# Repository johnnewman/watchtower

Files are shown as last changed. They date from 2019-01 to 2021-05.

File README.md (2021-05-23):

<p align="center">
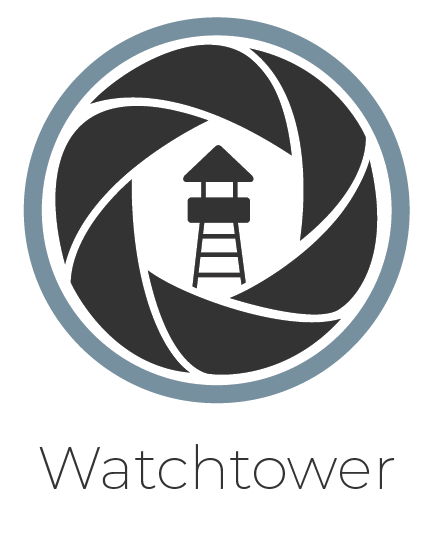
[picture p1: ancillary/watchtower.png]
  
</p>
<p class="aligncenter">

### Overview

Watchtower turns your Raspberry Pi into a DIY security camera. Watchtower scans for motion and, when triggered, will save a recording to disk in the h264 format and upload an encrypted copy to Dropbox. You can record to these destinations using different resolutions, which allows you to simultaneously record the full HD video to disk while recording a lower-resolution version to Dropbox.

The central [watchtower](watchtower) package is a Python 3 Flask app powered by uWSGI. It has API endpoints that allow you to start and stop monitoring, stream via MJPEG, record, download and delete recordings, and tweak camera settings. See [api.md](ancillary/api.md) for API documentation. This package also has an optional web app that provides a graphical interface for these APIs.

Watchtower was designed to take advantage of the Pi NoIR camera. An optional program for a microcontroller is included to read analog room brightness, control infrared LED intensity for night vision, move an optional servo, and communicate with Watchtower's microcontroller process using the Raspberry Pi's GPIO ports.

A 3D case for the system is located in [ancillary/case/](ancillary/case/). This case houses the Raspberry Pi, camera, microcontroller, servo, IR LEDs, fan, and more. A Fritzing diagram of the case's internal hardware is included in [ancillary/hardware/](ancillary/hardware).
<p align="center">
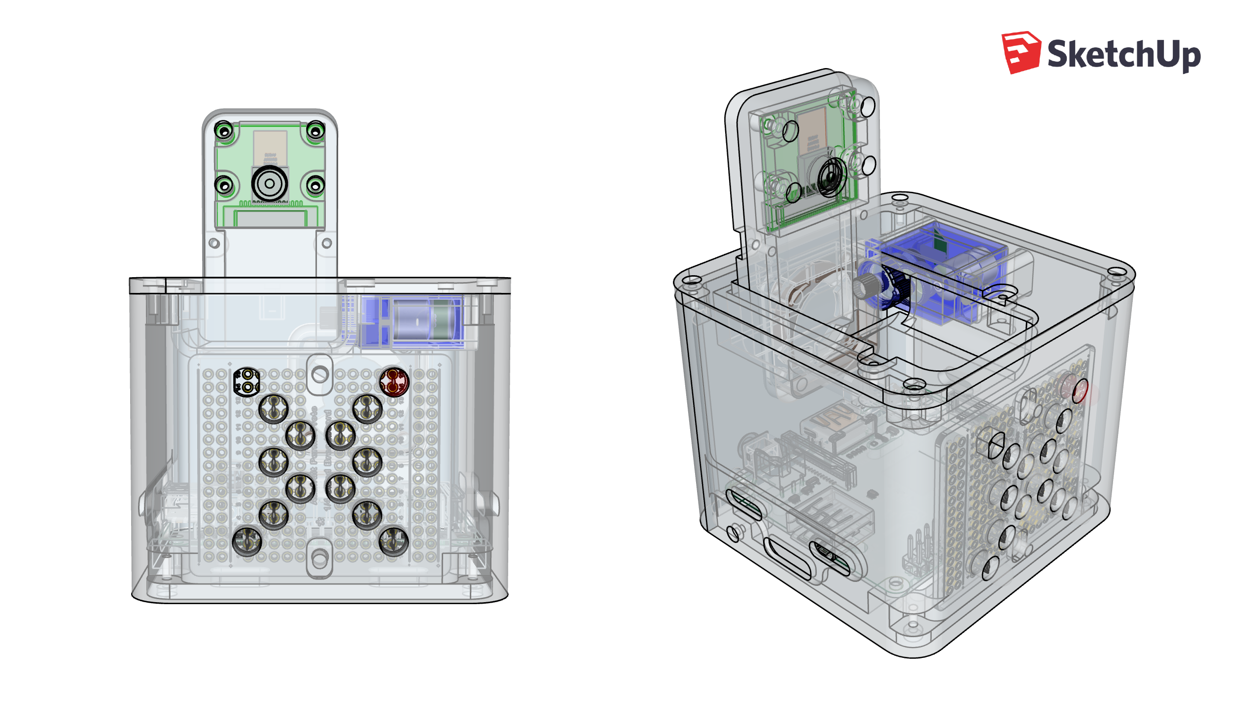
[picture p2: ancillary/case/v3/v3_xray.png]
    
</p>

### Setup

The Watchtower project is composed of multiple Docker containers that each carry out a specific function:
- the `app` container runs the main Watchtower package
- the `server` container runs an nginx app gateway and proxies requests to the `app` container
- the `motion` container continuously monitors the camera stream for motion
- the `mc_server` container communicates over a serial connection with an optional microcontroller
- the `icebox` container monitors the SoC temperature and controls an optional cooling fan via GPIO

_No container runs privileged as root. Only the minimum required access is provided to each container._

There is an included [install script](install.sh) for Raspberry Pi OS Lite that will set up Watchtower and place it behind a firewall. The install script only needs to be run once. After running, open a new shell session and run `docker-compose build` to build all of the containers. Finally, run ``docker-compose up -d` to start the application.

The final (and optional) steps outside of the script's scope are creating your SSL certificates for the web API and fine-tuning your Watchtower config file for Dropbox and microcontroller support.

Use the [WatchtowerServer project](https://github.com/johnnewman/watchtower_sever) as the main server that will handle traffic from the internet. That project is designed to proxy all requests to one of the upstream nginx servers running Watchtower. It can also coalesce the responses from all cameras into a single payload.

<p align="center">
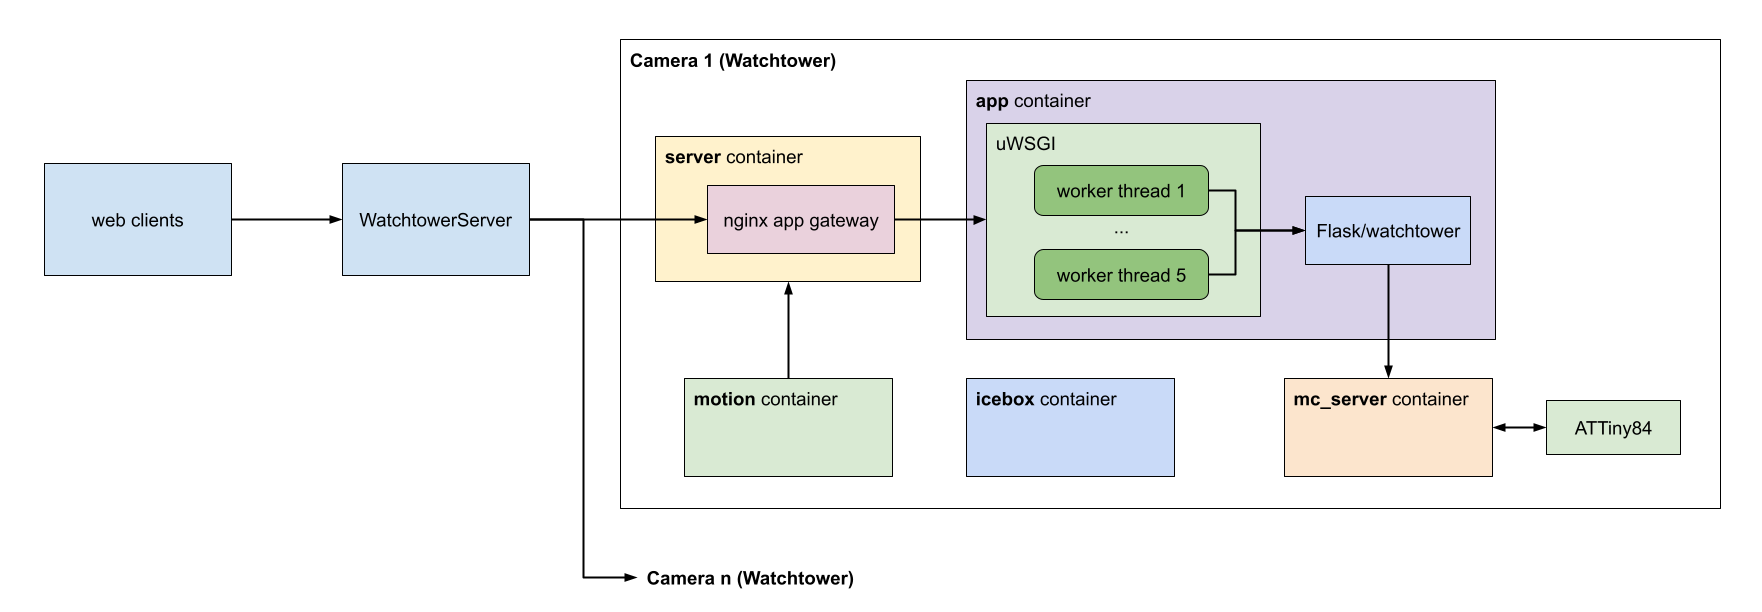
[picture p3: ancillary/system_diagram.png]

</p>

Both the reverse proxy and the upstream app gateway configurations encrypt all traffic and perform x509 client certificate authorization.

---

The rest of this readme breaks down each Watchtower component and describes its configuration. The three main configuration files are [config/watchtower_config.json](config/watchtower_config.json), [config/motion.conf](config/motion.conf), and the [.env](.env) file.
 1. [API endpoints](ancillary/api.md)
 2. [Front-end web app](#2-front-end-web-app)
 3. [Motion detection](#3-motion-detection)
 4. [Optional Dropbox file upload](#4-optional-dropbox-file-upload)
 5. [Optional microcontroller](#5-optional-microcontroller-infrared-and-servos)

### 1. API Endpoints

 Moved to [api.md](ancillary/api.md).

### 2. Front-end web app

An optional web app for each Pi's Watchtower instance can be enabled. You can access it in a browser through the reverse proxy by going to `https://proxy_address/camera0/`. This provides a simple interface for Watchtower built with [Bootstrap](https://getbootstrap.com/). 

The web app is broken into sections:
- The Home section lets you view the camera stream and toggle the monitoring status.
- The Recordings section displays a listing of all recordings that the Watchtower instance has saved. It allows you to delete and download individual recordings.
- The Settings section lets you tweak and save various settings of the Pi camera hardware.

| Home | Recordings | Settings |
| --- | --- | --- |
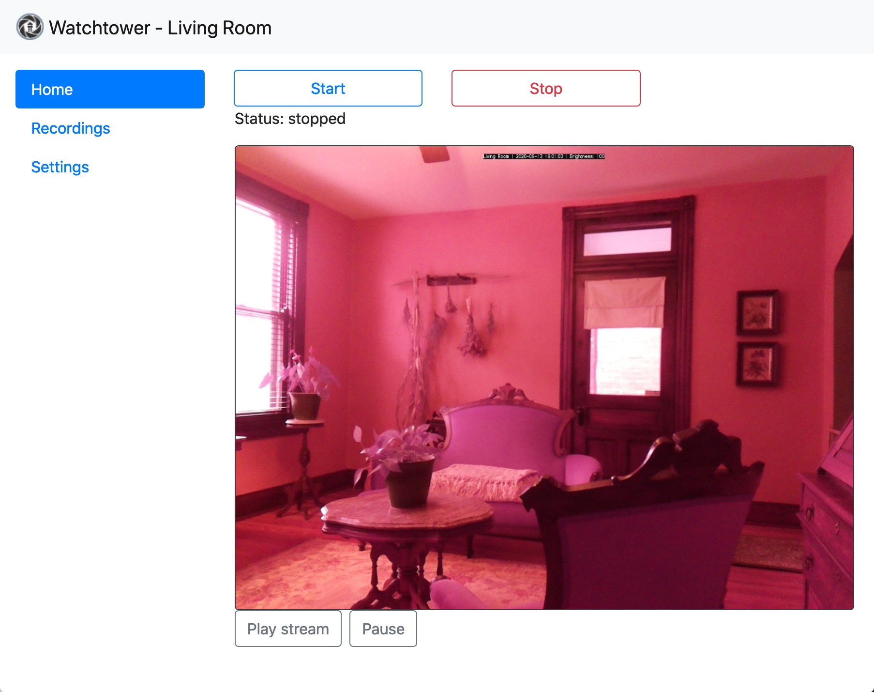
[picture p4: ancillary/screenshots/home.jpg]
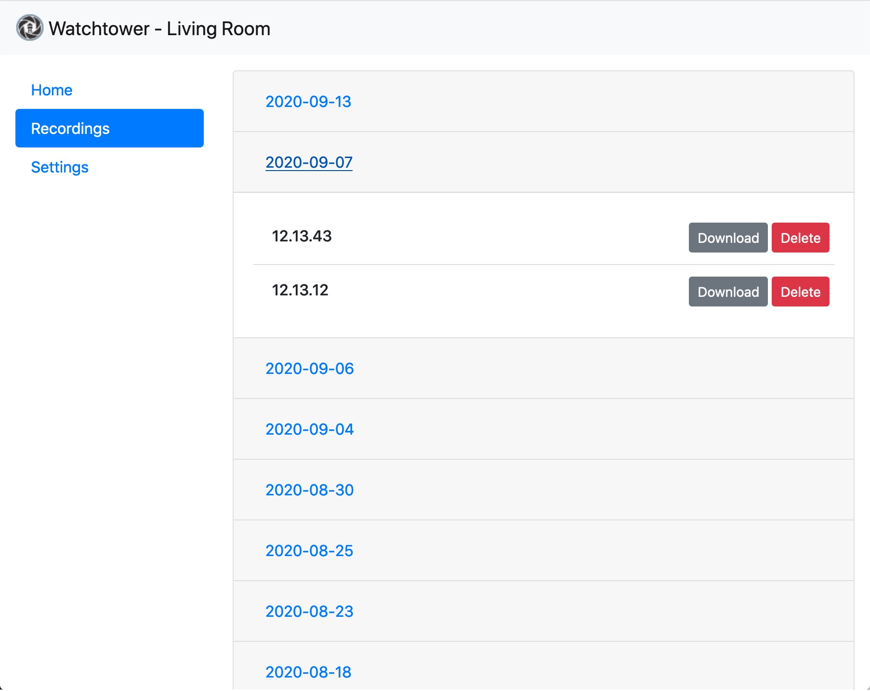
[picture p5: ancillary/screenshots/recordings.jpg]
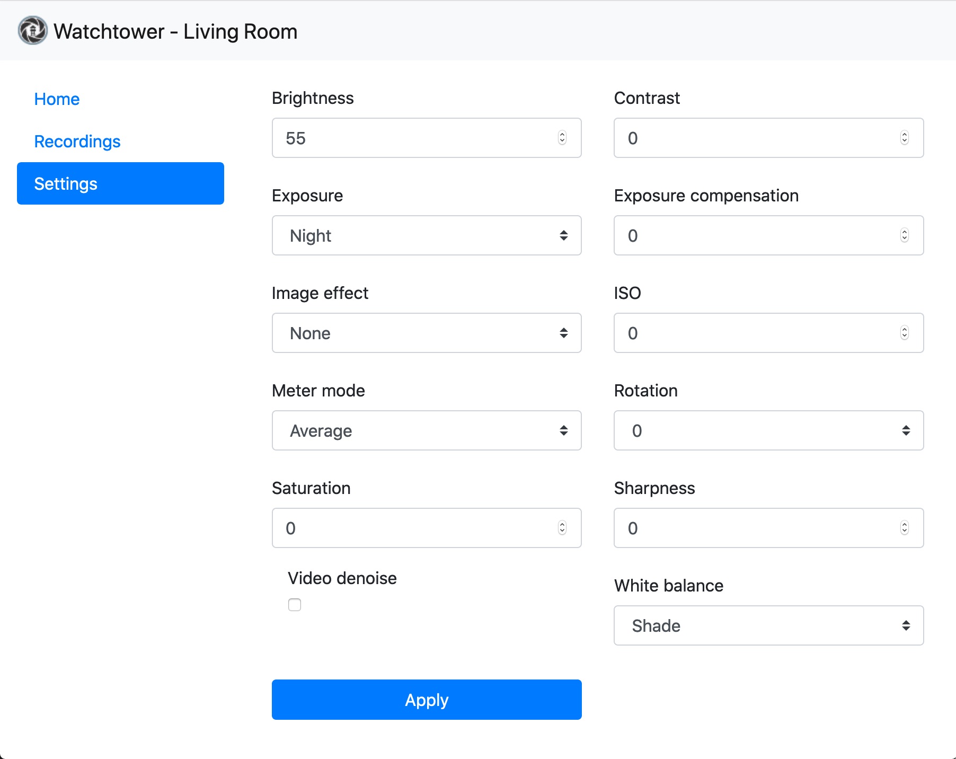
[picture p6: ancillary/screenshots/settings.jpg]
|  |  | |

<details>
  <summary><b>Configuration</b></summary>
  
There is only a single configuration option for the web app in the config JSON file. Omit or set `WEB_APP_ENABLED` to false to turn off the web app. When disabled, requests to load the app will 404.
</details>

### 3. Motion Detection

Frames from the camera feed are constantly monitored for changes using the open source [Motion](https://motion-project.github.io/) project. When Watchtower is started, the `motion` container connects to the `app` container using an MJPEG API only exposed to other Watchtower containers. This data is routed through the `server` container. While reading the MJPEG stream, if a large enough area of pixels has significantly changed, the `motion` container notifies the `app` container and an event is triggered. A JPEG capturing the instant that motion was detected will be saved along with the h264 video.

A nice feature of Motion is that it can learn the areas of the video that are subject to constant movement, like leaves swaying in the wind. It can also handle large changes in light that could have resulted from a light switch being flipped.

<details>
  <summary><b>Configuration</b></summary>

All motion detection settings are housed inside the `motion.conf` file. The full documentation on Motion's configuration options is listed [here](https://motion-project.github.io/motion_config.html#Configuration_OptionsAlpha). Be sure the width and height specified in `motion.conf` matches the `MJPEG_SIZE` specified in `watchtower_config.json`.

Two useful configurations in `watchtower_config.json` are:
- `MAX_EVENT_TIME` the maximum number of seconds for a single recording.
- `RECORDING_PADDING` the number of seconds to record before and after motion occurs.
</details>

### 4. Optional Dropbox File Upload

Video files are sent to Dropbox in small chunks as soon as motion is detected. For playback, the data will need to be concatenated into a single file. To help with this, a shell script located at [ancillary/mp4_wrapper.sh](ancillary/mp4_wrapper.sh) will combine the videos for each motion event into one file and will convert the h264 format into mp4 using [MP4Box](https://gpac.wp.imt.fr/mp4box/). MP4Box only needs to be installed on the machine that opens recordings from Dropbox; no need to install it alongside any Watchtower instance.

The video files uploaded to Dropbox can be encrypted using symmetric key encryption. Simply supply a path in the config JSON file to a public asymmetric encryption key in PEM format. When this path is supplied, a symmetric [Fernet](https://cryptography.io/en/latest/fernet.html) key is generated for each file uploaded. This new key will be used to encrypt the contents of its file and then it will itself be encrypted using the supplied public key. This encrypted key is base64 encoded and padded onto the beginning of the Dropbox file. The resulting file data has the format: `{key_length_int} {encoded_and_encrypted_key}{encrypted_data}`. [mp4_wrapper.sh](ancillary/mp4_wrapper.sh) can accept a path to the asymmetric private key and will automatically decrypt the files before stitching them together and converting the final video to an mp4.

<details>
  <summary><b>Configuration</b></summary>

All Dropbox properties are contained inside the `dropbox` key of the `DESTINATIONS` object in the config JSON file. Dropbox can be disabled by deleting the `dropbox` entry.
- `file_chunk_kb` determines the maximum file size in kilobytes that will be uploaded to Dropbox. Files are saved in series using the name `video#.h264` like `video0.h264`, `video1.h264`, etc.
- `token` is the Dropbox API token for your account.
- `public_key_path` the path to the public asymmetric key. If `null` is supplied or this field is omitted, the Dropbox files are not encrypted.
- `size` is an array containing the width and height of the videos saved to Dropbox. This is useful for specifying a smaller size for Dropbox, saving storage and network resources. 
</details>

### 5. Optional Microcontroller, Infrared, and Servos

The project can be optionally configured to work with a microcontroller to enable and disable infrared lighting for night vision. The controller also reads the analog room brightness and uses pulse-width modulation to fine-tune the infrared brightness. The brightness will be displayed in the camera's annotation area along with the camera name and the current time. In the event that the camera should rotate or be covered when not in use, this controller can also move an attached servo. A diagram for the microcontroller circuit [is included](/ancillary/hardware).

I used an AVR ATTiny84 for its small size and low price. This microcontroller has more than enough IO ports for Watchtower and it comes with a second internal timer that can be dedicated for 50Hz servo usage.

The ATTiny84 program located in [microcontroller/arduino/controller.ino](microcontroller/arduino/controller.ino) is configured to communicate serially with the `mc_server` Docker container. Along with the [TinyServo](microcontroller/arduino/TinyServo.h) library, the AVR program consumes about 3.6KB of program space if link time optimization (LTO) is used, and about 4.5KB without LTO. Either approach works fine with the ATTiny84's 8KB of program space. [ATTinyCore](https://github.com/SpenceKonde/ATTinyCore) is a great project that you can use with the Arduino IDE to program the ATTiny microcontroller. The [hardware section](ancillary/hardware) describes how to program the ATTiny84 with ICSP using the Raspberry Pi. This allows you to reprogram the microcontroller without disassembling the case. The necessary connections for this are included in the circuit diagram.

<details>
  <summary><b>Configuration</b></summary>

The two configurations in the config JSON file are:
- `SERVO_ANGLE_ON` the angle (from 0-180) of the servo for the on state.
- `SERVO_ANGLE_OFF` the angle (from 0-180) of the servo for the off state.

The rest are configurations are located in the [.env](.env) file:

- `SERIAL_ENABLED` if `0`, the `mc_server` Docker container will not be used.
- `SERIAL_BAUD` is the baud rate of the serial connection with the microcontroller.
- `SERIAL_DEVICE` is the location of the serial connection, like `/dev/serial0` on Raspberry Pi OS.
- `MC_SERVER_PORT` is the port number used for the Watchtower container to communicate with the microcontroller container. This should not need to be changed.
</details>

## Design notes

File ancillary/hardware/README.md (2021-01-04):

# Hardware

Watchtower uses two Adafruit prototyping boards and one AVR microcontroller:
- Perma-Proto HAT
   - https://www.adafruit.com/product/2310
   - [Fritzing file](https://github.com/adafruit/Fritzing-Library/blob/master/parts/Adafruit%20Perma-Proto%20HAT.fzpz)
- PermaProto Quarter-sized breadboard
   - https://www.adafruit.com/product/1608
   - [Fritzing file](https://github.com/adafruit/Fritzing-Library/blob/master/parts/PermaprotoQuarterBoard.fzpz)
- ATTiny84A
   - https://www.digikey.com/product-detail/en/microchip-technology/ATTINY84A-PU/ATTINY84A-PU-ND/2774082
   - [Fritzing file](https://github.com/brucetsao/Fritzing/blob/master/ATTiny84-HLT-core.fzpz)

The Perma-Proto HAT sits on top of the Raspberry Pi and contains ports to run the servo, front IR panel, status LED, photoresistor, and case fan. This setup will all fit inside the [case included with the project](../case). The front status LED helps the user know that the infrared lights are turned off. It is connected to the same PWM line as the IR LEDs, so its brightness will update with the front IR panel.

_I'm not an electrical engineer, but this setup has worked well for me._

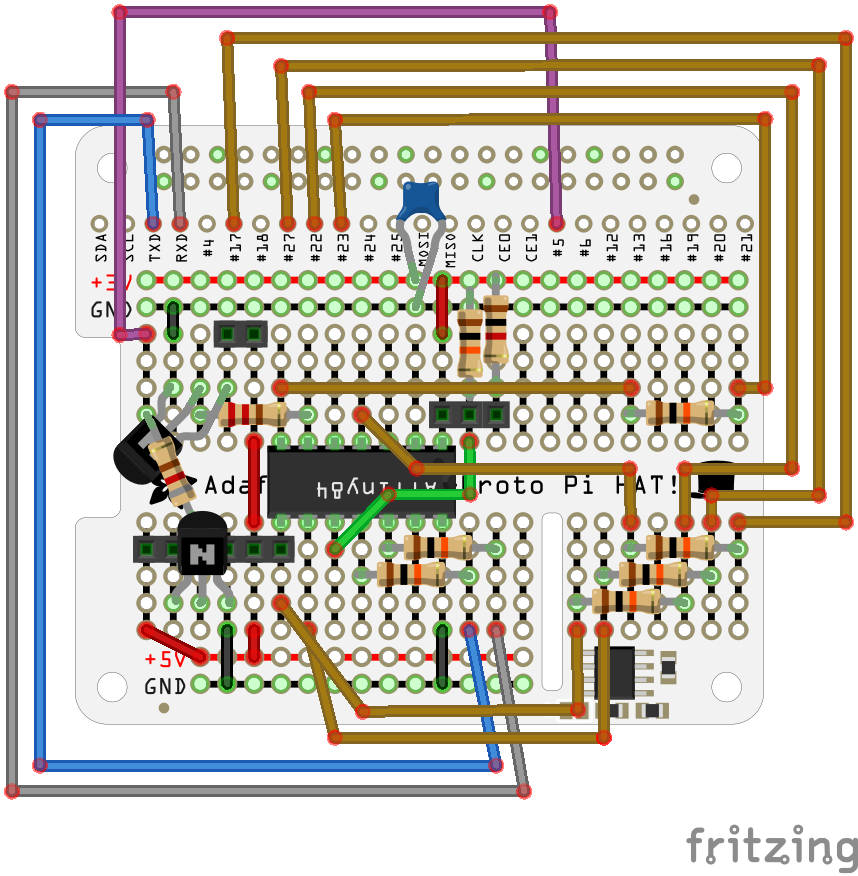
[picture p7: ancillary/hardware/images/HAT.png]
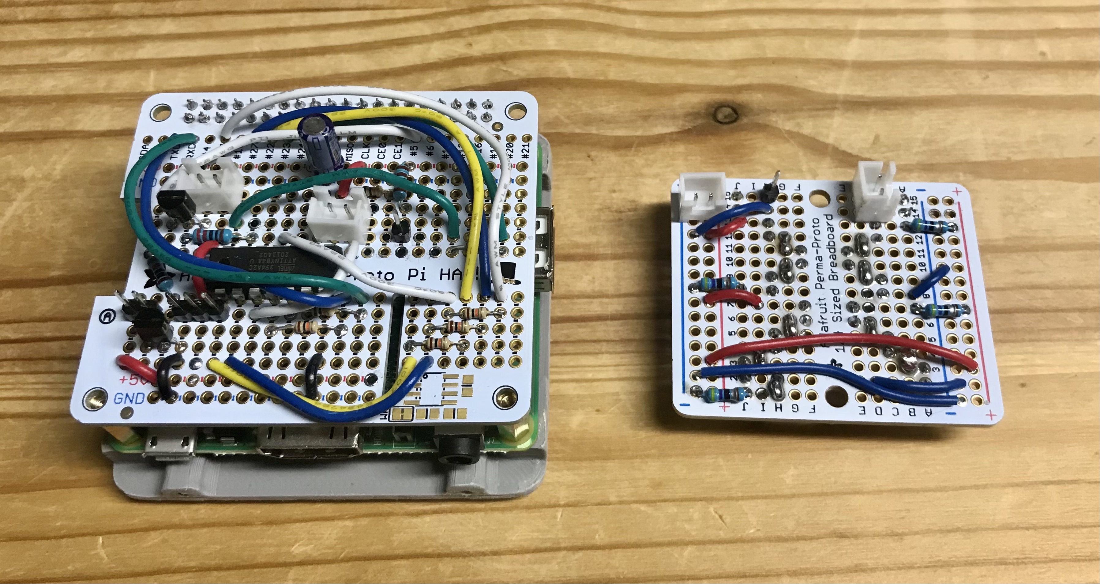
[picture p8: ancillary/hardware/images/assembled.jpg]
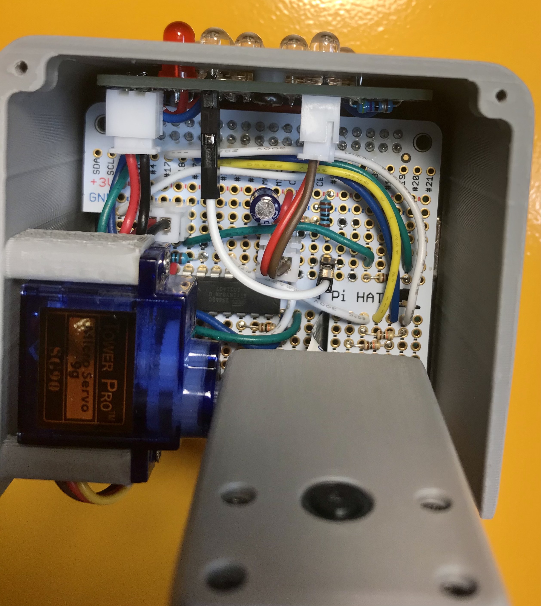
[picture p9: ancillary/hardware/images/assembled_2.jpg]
  

The microcontroller, photoresistor, and status LED are all powered from the 3V rail. The IR LEDs, case fan, and servo are powered from Pi's 5V rail. There are two transistors on the board that are both used as "full on" switches. One transistor can turn the fan on and off from the Pi's GPIO pin 5. The other transistor is connected to the ground line for all of the LEDs. Its base pin is connected to PWM pin 6 on the ATTiny84. This allows the microcontroller to adjust the brightness of all the LEDs. Both transistors are NPN S8050's which can handle the high power requirements of the front panel. Anything can work here as long as the transistors can handle the power requirements.

Watchtower uses [Icebox](https://github.com/johnnewman/icebox/) to control the fan. This is automatically installed using Watchtower's install script. Icebox will power on the fan only when the SoC temperature reaches a certain threshold. Once the SoC cools back down, the fan will be powered off.

Lines to the Raspberry Pi's GPIO pins 17, 27, 22, and 23 are included for ICSP reprogramming of the ATTiny84. This way you don't need to take apart the case to update the microcontroller's software. The pins for the ATTiny84 are broken down [here](https://github.com/SpenceKonde/ATTinyCore/blob/master/avr/extras/ATtiny_x4.md) in ATTinyCore.

All lines between the Pi and the Microcontroller (serial and ICSP) are connected to a 10kΩ resistor. This keeps the lines from pulling more than 0.33mA.

A decoupling capacitor is located on the 3V line to help mitigate noise or voltage drop that might occur while the device is running. [ATTinyCore](https://github.com/SpenceKonde/ATTinyCore) recommends a 0.1uF capacitor. A ceramic capacitor is best since it has the fastest response to voltage changes.

### Power Requirements

- The front IR panel consumes around 400mA of power when using 100mA IR LEDs.
   - There are 12 infrared LEDs total. Of those, there are 4 parallel circuits that contain 3 LEDs in series. With 100mA LEDS, those 4 parallel circuits pull 400mA. The status LED only pulls 3mA.
- The 30x30mm fan I am using has a current draw of 120mA.
- A Pi 3B+ [typical bare-board draw is 500mA](https://www.raspberrypi.org/documentation/hardware/raspberrypi/power/README.md). Under stress, [this can average 850mA](https://www.raspberrypi.org/documentation/faqs/#power).
- The Pi Camera pulls 250mA.

400mA IR + 120mA fan + 850mA Pi 3A/B + 250mA Camera = **1620mA total**.

This isn't factoring in the ATTiny84's current draw at 3V, but this should be negligible. A 2500mA power supply will have plenty of headroom for the micro servo, which will be running in short bursts and will have very little physical resistance when it moves.

### ICSP Instructions (optional)

To program the ATTiny84 using the Raspberry Pi, you will need to compile AVRDUDE with linuxgpio support. This allows AVRDUDE to flash the microcontroller using the Raspberry Pi's GPIO ports. AVRDUDE 6.3 has a bug with linuxgpio, so I am using 6.2.

Commands to install AVRDUDE:
```Bash
sudo apt install bison flex
wget http://download.savannah.gnu.org/releases/avrdude/avrdude-6.2.tar.gz
tar xfv avrdude-6.2.tar.gz 
cd avrdude-6.2/
./configure --enable-linuxgpio
make
sudo make install
sudo nano /usr/local/etc/avrdude.conf 
```
When editing `avrdude.conf`, find the commented out linuxgpio programmer, uncomment it, and update the pin numbers to match the Watchtower setup:
```
programmer
  id    = "linuxgpio";
  desc  = "Use the Linux sysfs interface to bitbang GPIO lines";
  type  = "linuxgpio";
  reset = 17;
  sck   = 27;
  mosi  = 23;
  miso  = 22;
;
```

Now run `sudo avrdude -c linuxgpio -p t84 -v` and you should see output indicating a successful connection to the ATTiny84.

#### Initial setup

To set the clock to 8MHz and enable brown out detection at 2.7 volts:
```Bash
wget https://github.com/SpenceKonde/ATTinyCore/archive/1.4,1_manual.zip
unzip 1.4,1_manual.zip
sudo avrdude -c linuxgpio -p t84 -v -b19200 -e -Uefuse:w:0xFF:m -Uhfuse:w:0b11010101:m -Ulfuse:w:0xE2:m -Uflash:w:ATTinyCore-1.4-1_manual/avr/bootloaders/empty/empty_all.hex:i 
```

You can view this command within the Arduino IDE if you have the [ATTinyCore](https://github.com/SpenceKonde/ATTinyCore) boards installed. Go to Tools > Burn Bootloader with the ATTiny84 board selected:

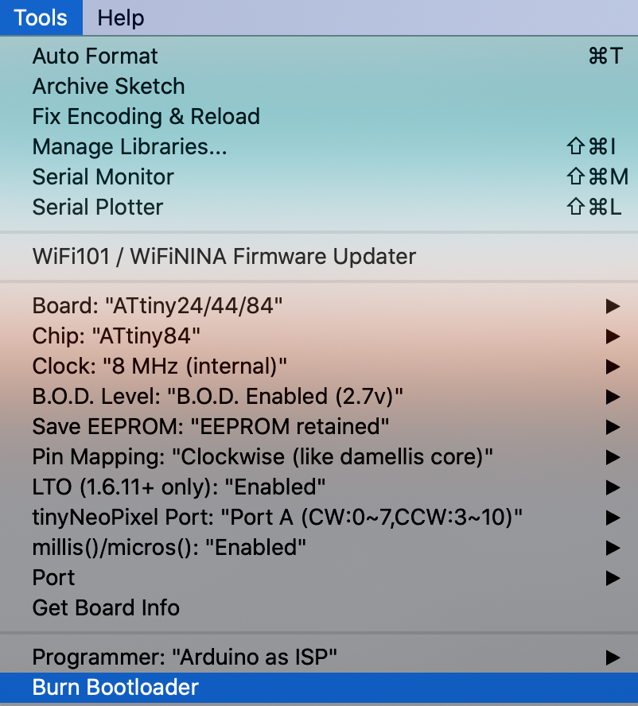
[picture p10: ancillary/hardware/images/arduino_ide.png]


With verbose logging enabled, you will see the above command in the Arduino console.

#### Installing `controller.ino`

To flash the microcontroller with the [`controller.ino`](../../microcontroller/arduino/controller.ino) program, you'll need to compile it with the Arduino IDE on any computer. Enable verbose logging in Arduino and attempt to upload the program. You will see a command similar to the following in the console:
```
avrdude ... -Uflash:w:/var/folders/wd/.../controller.ino.hex:i 
```
You can copy the `controller.ino.hex` file from that directory and transfer it to your Raspberry Pi. From there, flash the ATTiny84 with the command:
```Bash
sudo avrdude -c linuxgpio -p t84 -v -b19200 -Uflash:w:controller.ino.hex:i
```

You should see output from AVRDUDE indicating that the program was successfully uploaded and verified. At this point, you are finished!

### Full diagram:
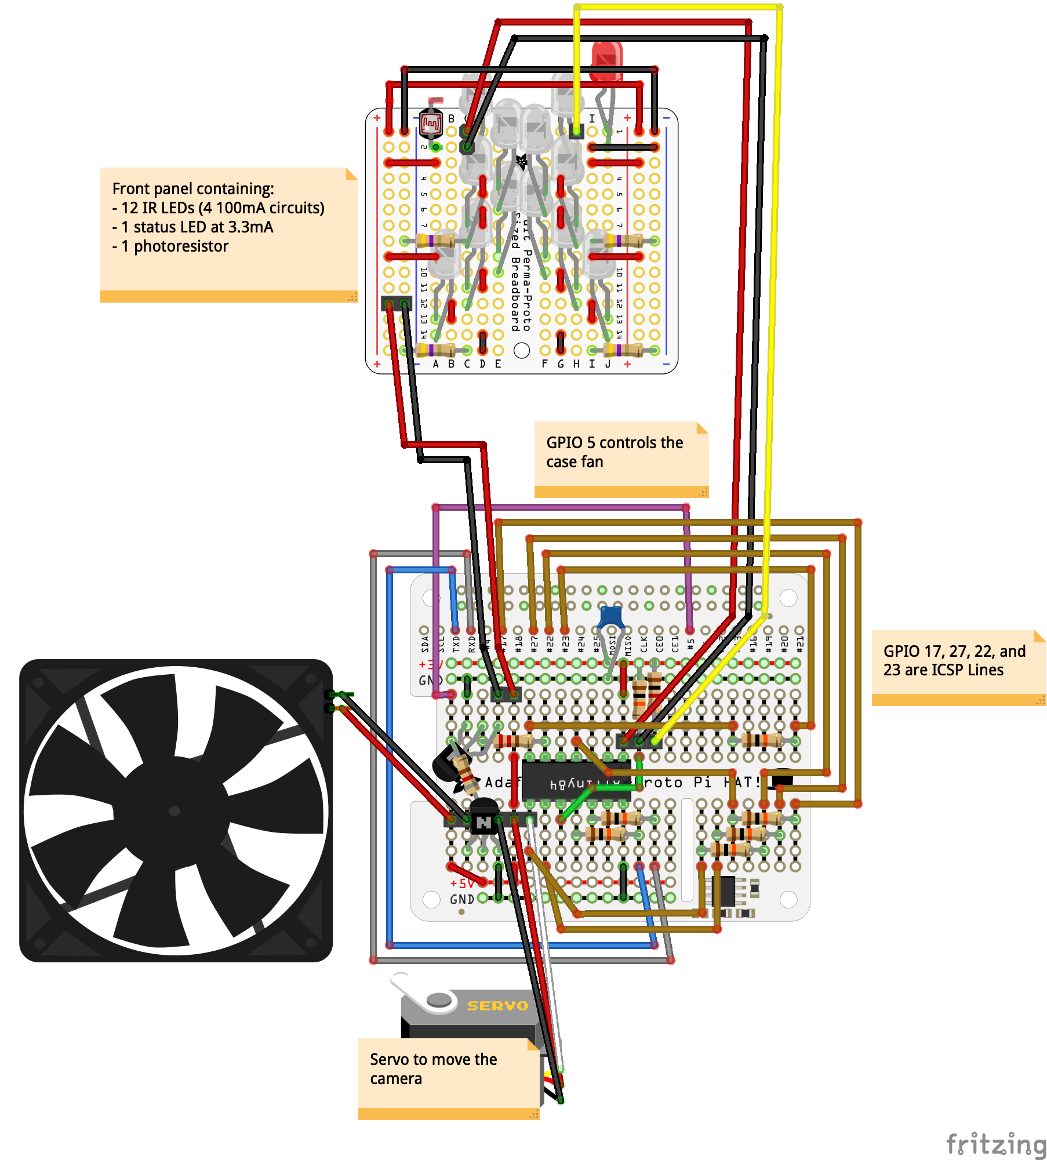
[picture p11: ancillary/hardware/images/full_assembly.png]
Full diagram


### HAT connections:
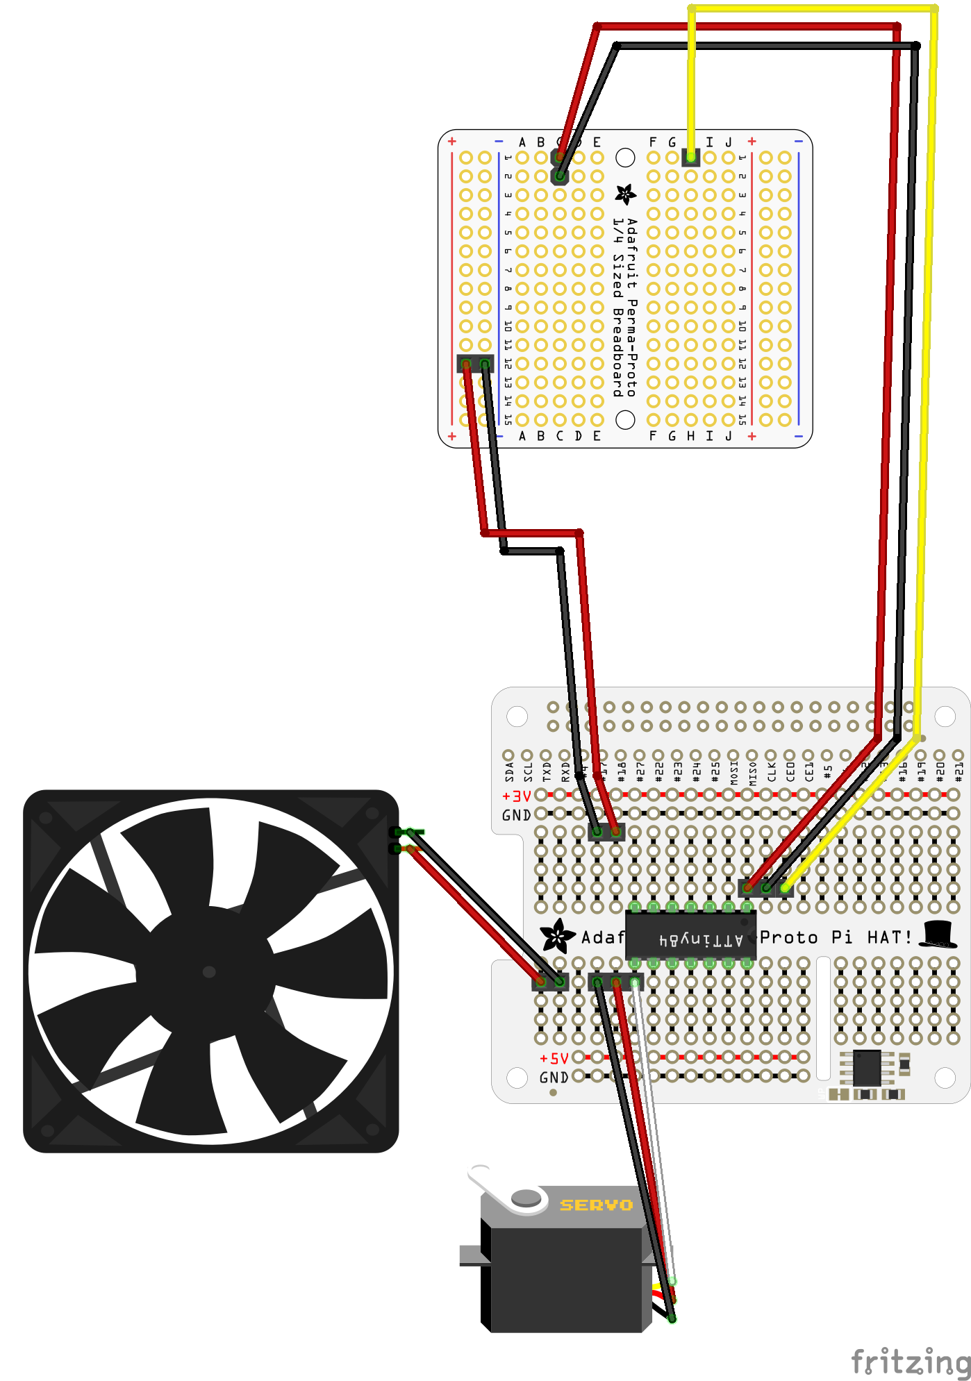
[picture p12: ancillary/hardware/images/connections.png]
Board Connections


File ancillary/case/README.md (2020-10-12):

# System case

The cases for Watchtower are housed within their versioned folders here. You can check out the full model of v3 [here](./v3/parts/v3_all_parts.stl).

### All versions:

For extra peace of mind, the camera is connected to a servo which will conceal the camera inside the case when not in use. The case contains holes in the front that match the configuration of the IR panel described in the [hardware section](../hardware).

A mounting cradle for the micro servo is located on the right side panel. The SG92R servo is what I use: https://www.adafruit.com/product/169. The servo will rotate the camera housing to expose the camera when the system is turned on.

The system is self-contained except for a space for the power cable. A Raspberry Pi 3+ is necessary for the on-board WiFi.

### Version 3:

- Designed for the Raspberry Pi 3A+ form factor.
- Roughly 47% smaller than v1 and 22% smaller than v2.
- The photoresistor and status LED have been moved onto the front circuit board. Two front LEDs have been removed to make space.
- The exhaust fan has been moved to the back of the case. Using heatsinks, the fan can cool the SoC from 53C to 38C in 5 minutes in a 70F/21C room while running Watchtower.
- The bottom panel's screws have been moved to make it easier to slide the bottom panel into the case from the rear.
- Air intake vents added to the left side to match the right side.
- **Contains all of the same improvements that were introduced in version 2.**

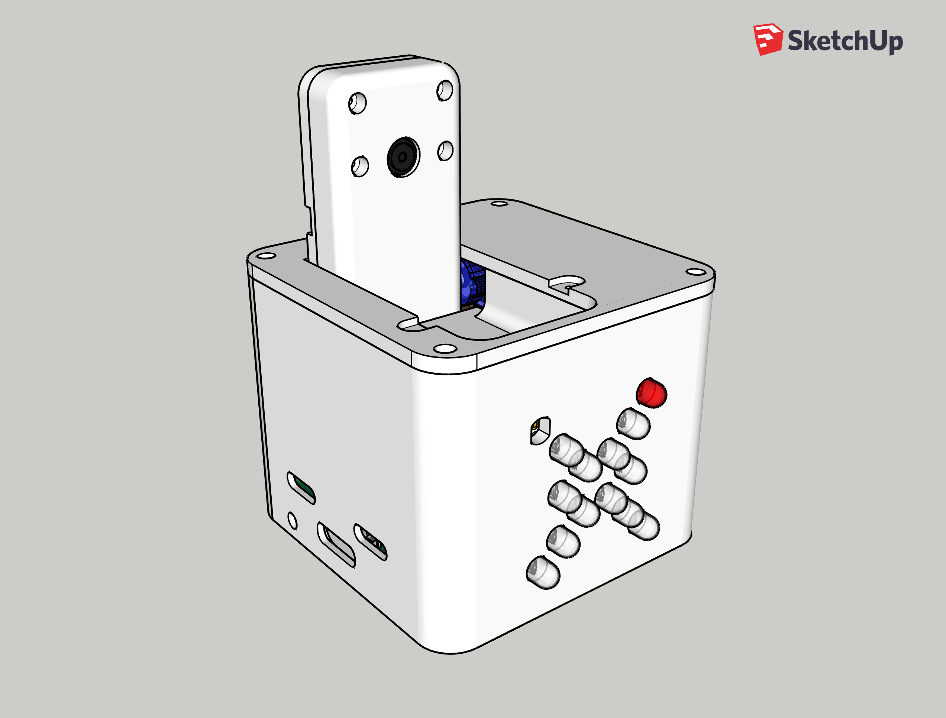
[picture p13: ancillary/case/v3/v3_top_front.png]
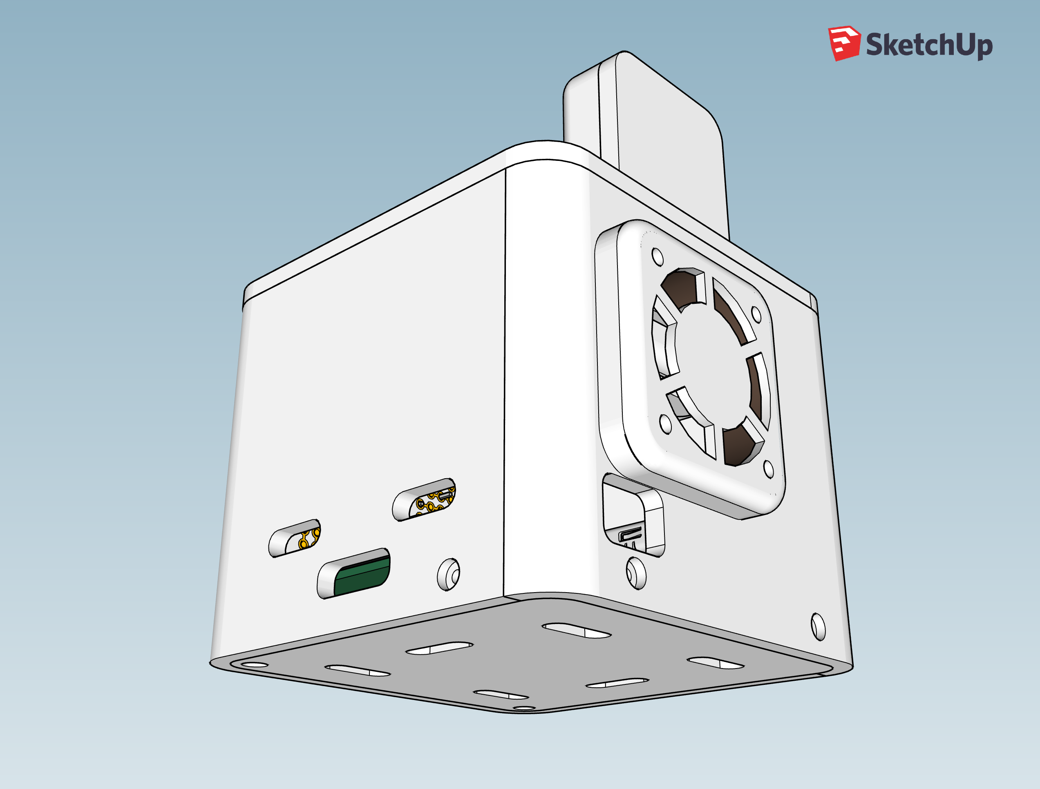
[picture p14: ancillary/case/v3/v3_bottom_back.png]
 
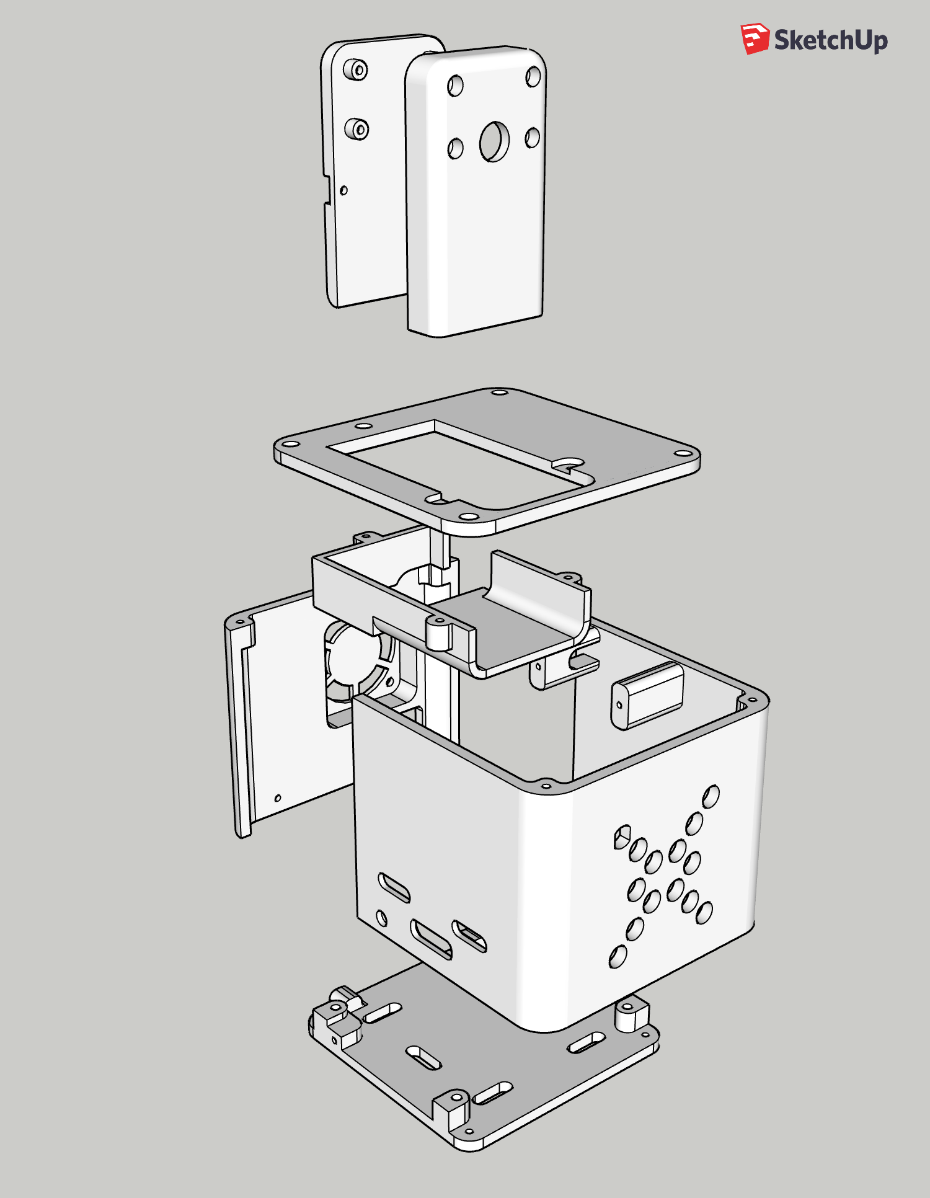
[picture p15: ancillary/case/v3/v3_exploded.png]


Version 3 and version 2 side-by-side:

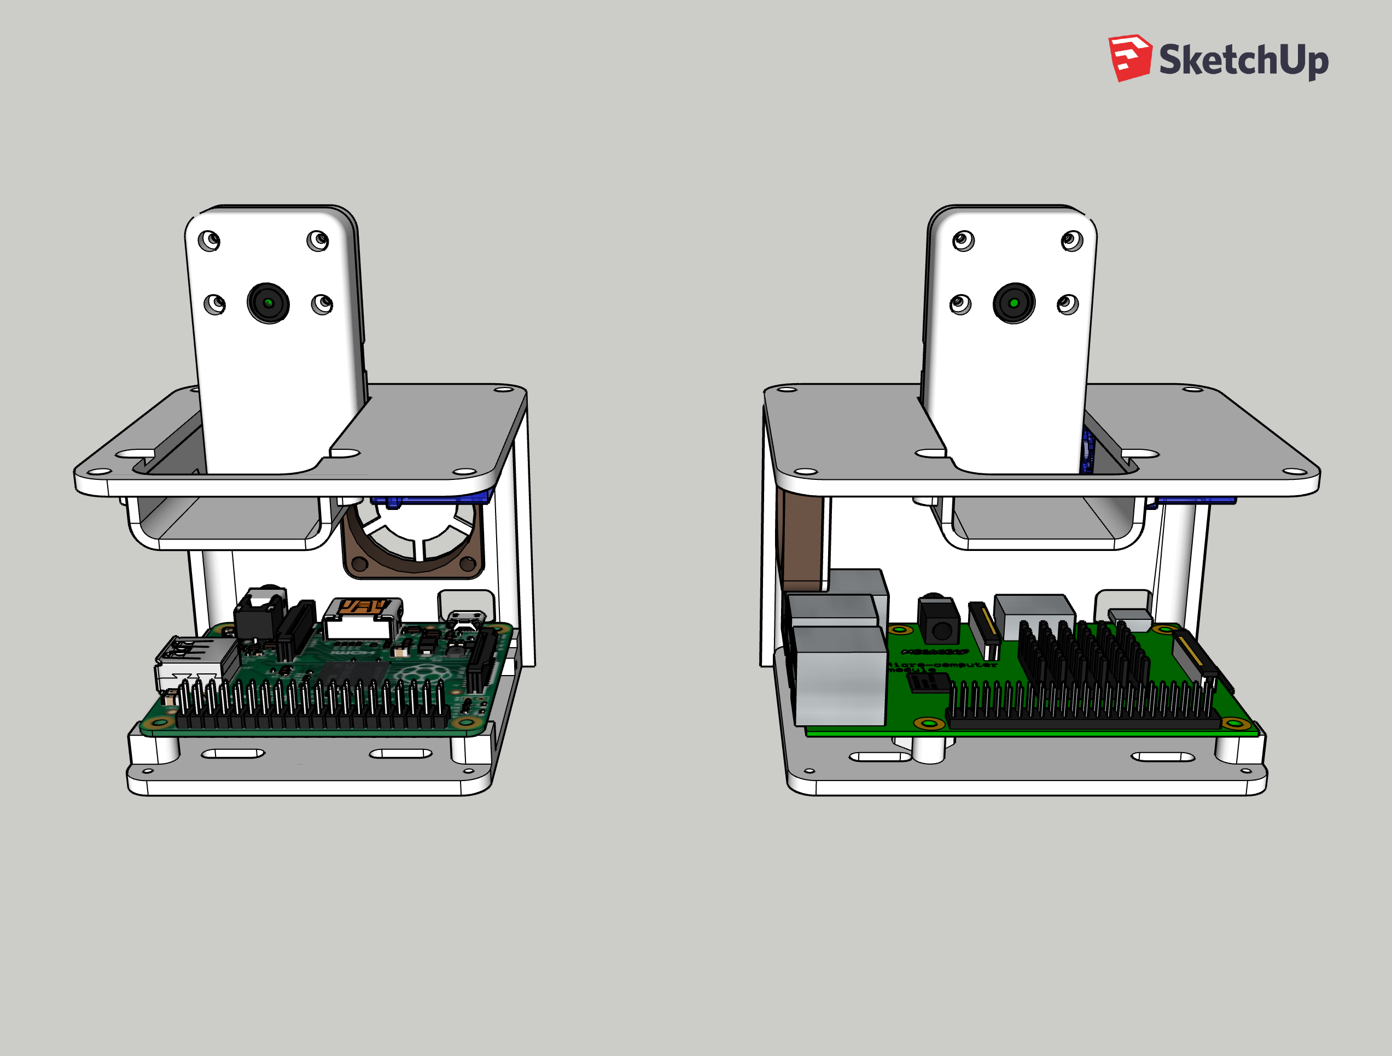
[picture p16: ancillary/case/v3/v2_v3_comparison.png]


### Version 2:

- 32% smaller than version 1.
- Uses M2x6 screws to tightly seal all of its panels.
- Comes with mounts on the left side panel for a 30x30mm fan to cool the system.
- The top panel has a closer seal around the camera's case.
- The servo's mouting gear attaches directly to the camera's case instead of needing to use a plastic arm that comes with the servo.
- There is a cradle underneath the camera that v1 does not have. This keeps the camera mount from being damaged if pressure is applied to the top of the case or if the servo is rotated beyond its closed angle.

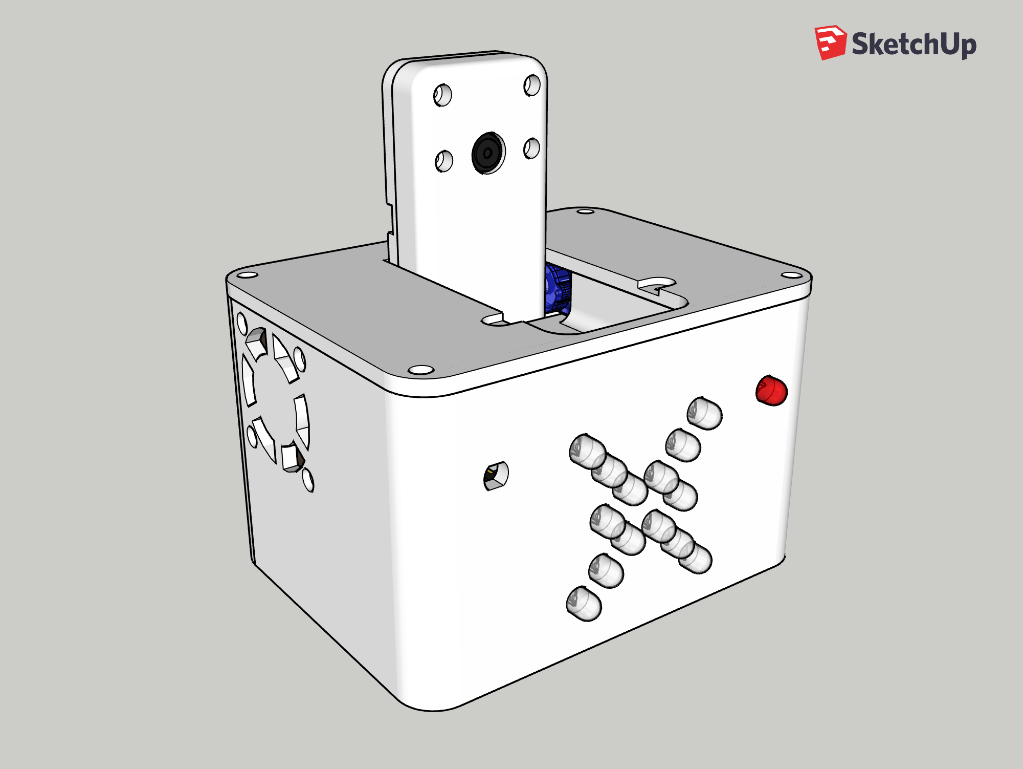
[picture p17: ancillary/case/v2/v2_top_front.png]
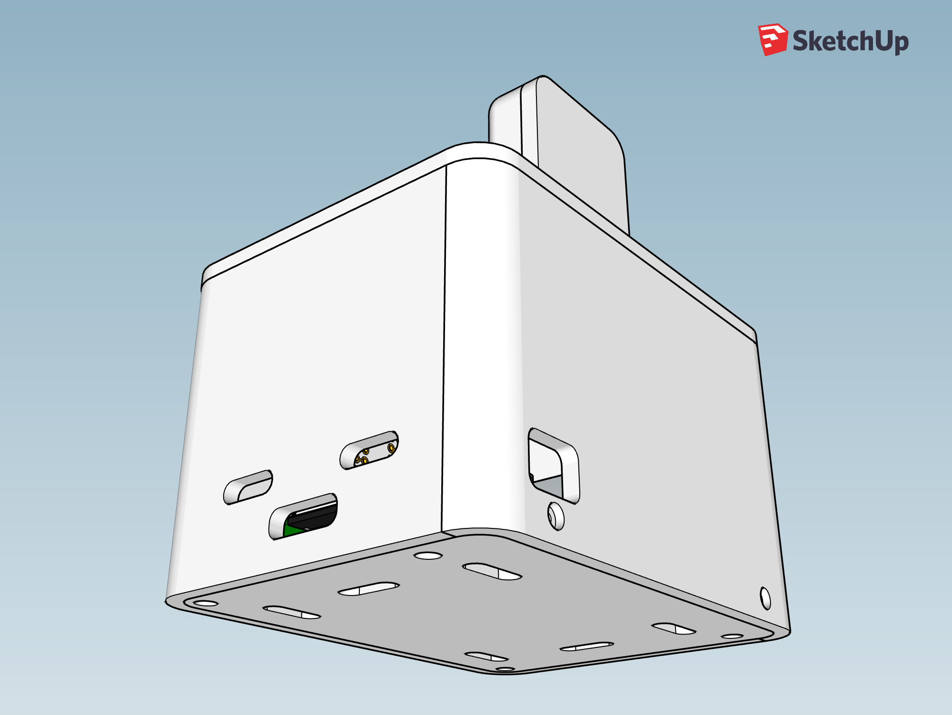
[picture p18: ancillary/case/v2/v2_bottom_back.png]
 
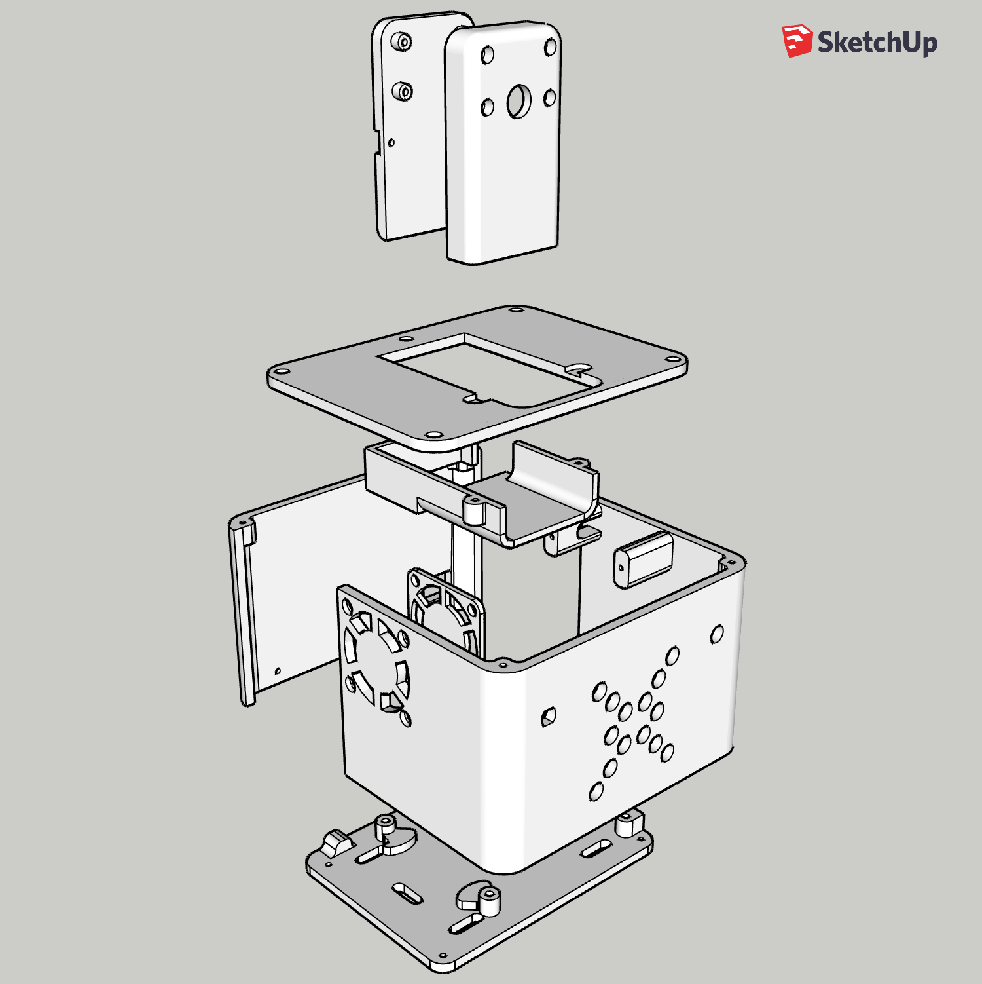
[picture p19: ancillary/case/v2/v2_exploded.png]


### Version 1:

This is an obsolete design that's much larger. It doesn't have any protection for the camera if pressure happens to be applied to the top of the case. This can cause the camera to rotate into the case or possibly break from the servo.

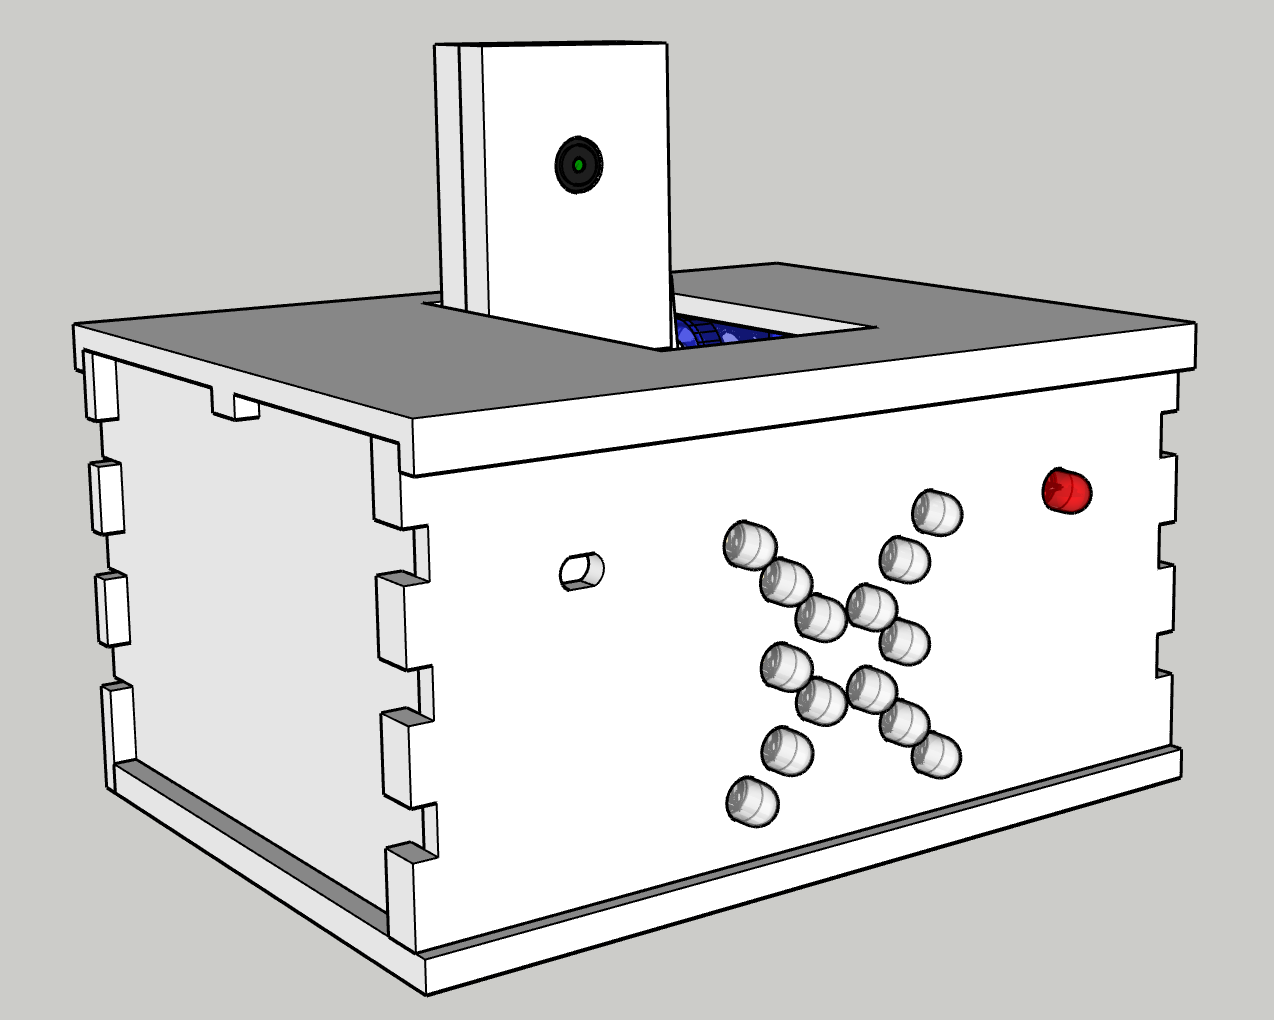
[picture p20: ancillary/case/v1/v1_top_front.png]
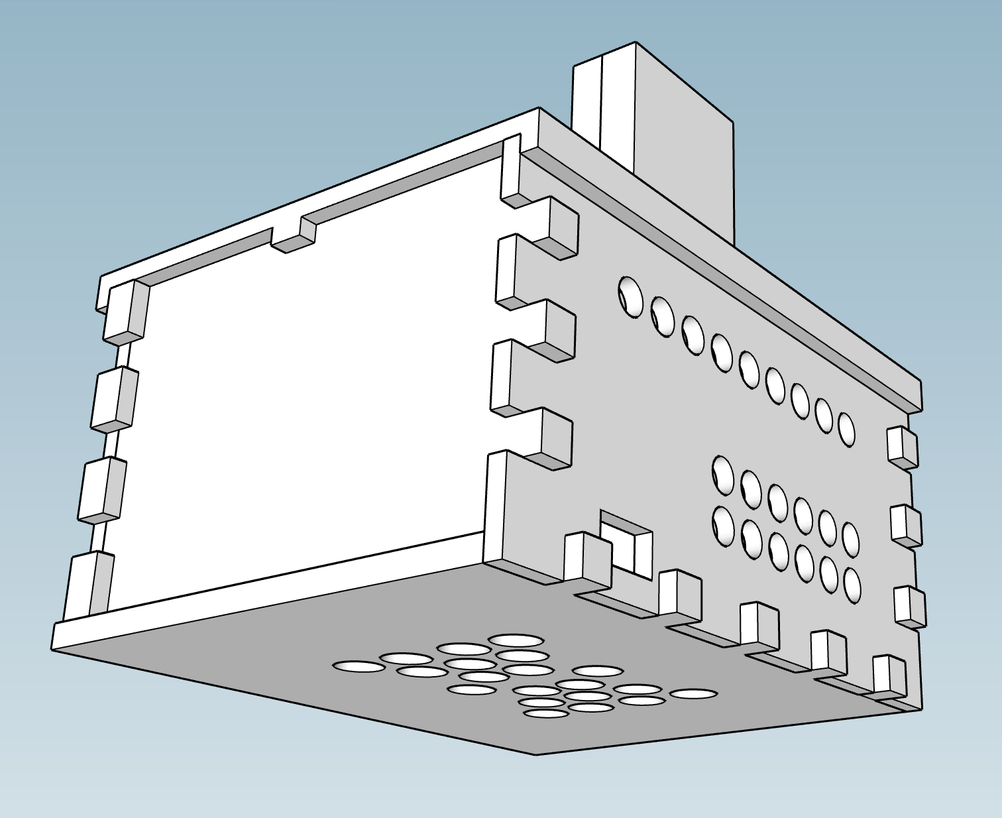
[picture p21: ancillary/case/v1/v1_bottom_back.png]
 
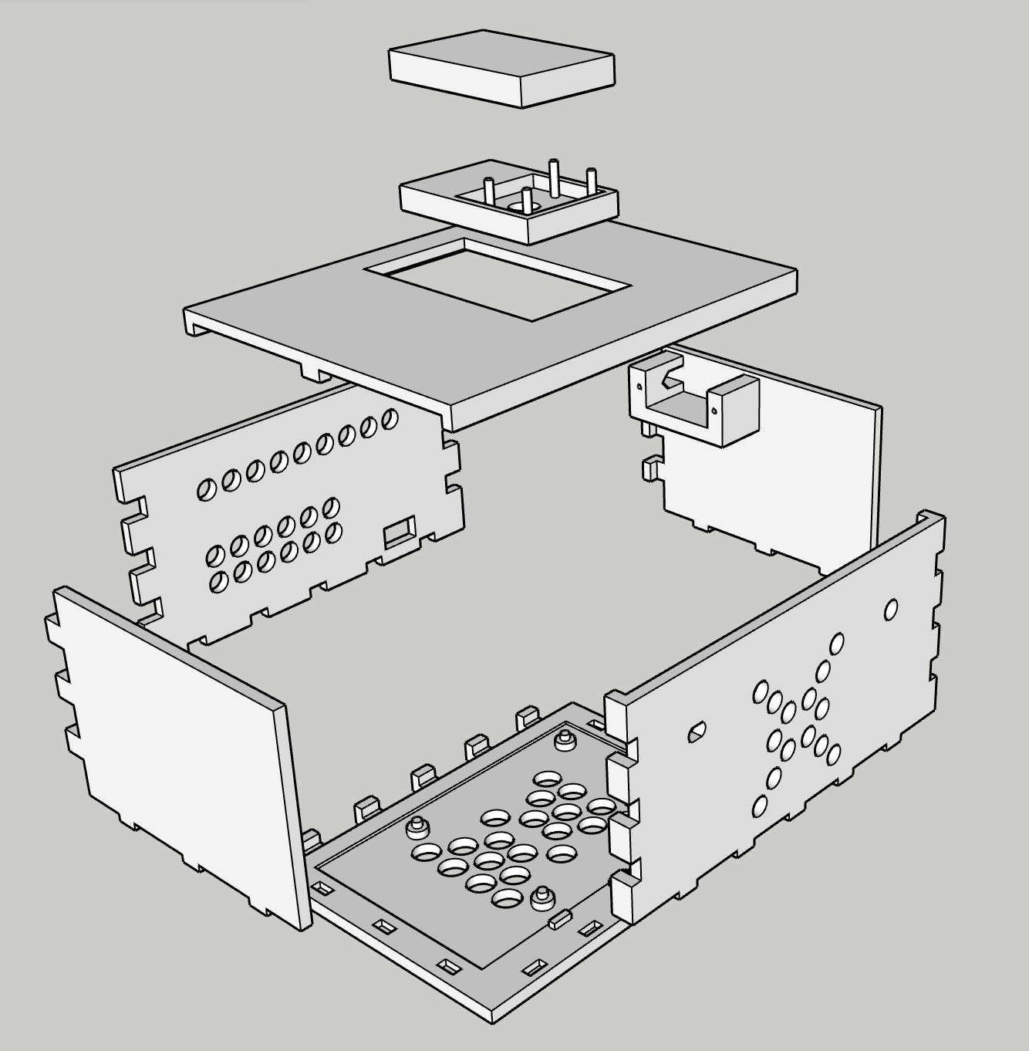
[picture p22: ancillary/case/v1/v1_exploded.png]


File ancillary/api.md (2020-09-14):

# Watchtower HTTP API

### GET `/api/status` 

Returns the current monitoring status of Watchtower.

#### 200 Response JSON:
```JSON
{
    "monitoring": true
}
```

### GET `/api/start`

Starts monitoring the camera feed for motion. If the optional microcontroller is used, it will be signaled to move its servo to the on position and start monitoring the room brightness to control infrared lighting.

The response will match the format of the `/status` response.

#### 200 Response JSON:
```JSON
{
    "monitoring": true
}
```

### GET `/api/stop`

Stops monitoring the camera feed for motion. If the optional microcontroller is used, it will be signaled to move its servo to the off position and stop monitoring the room brightness to control infrared lighting. The infrared lighting will be turned off.

The `/stop` endpoint is the exact opposite of `/start`.

#### 200 Response JSON:
```JSON
{
    "monitoring": false
}
```

### GET `/api/config`

Returns the Pi camera's current image configuration. Without having made any configuration changes, this will return default values for [PiCamera](https://picamera.readthedocs.io/en/release-1.13/api_camera.html). Otherwise, these values will match the custom configuraiton preferences saved to `camera_config.json`, which are loaded and applied when Watchtower boots. This file is created and maintained automatically by Watchtower.

#### 200 Response JSON:

```JSON
{
    "awb_mode": "auto",
    "brightness": 50,
    "contrast": 0,
    "exposure_compensation": 0,
    "exposure_mode": "auto",
    "image_effect": "none",
    "iso": 0,
    "meter_mode": "average",
    "rotation": 0,
    "saturation": 0,
    "sharpness": 0,
    "video_denoise": true
}
```

### POST `/api/config`

Sets the Pi camera's image configuration settings. Any number of these fields can be sent in the POST, no need to send all of them. When changed, the new configuration will be saved to `camera_config.json` located in the Flask instance folder. Any changes will go into effect immediately, even while recording or streaming is taking place. The next time the system reboots, the updated `camera_config.json` file will be used, so these values don't need to be repeatedly reset.

#### Request JSON:

```JSON
{
    "awb_mode": "shade",
    "brightness":55,
    "exposure_mode": "night"
}
```

#### 200 Response JSON:

```JSON
{
    "awb_mode": "shade",
    "brightness": 55,
    "contrast": 0,
    "exposure_compensation": 0,
    "exposure_mode": "night",
    "image_effect": "none",
    "iso": 0,
    "meter_mode": "average",
    "rotation": 0,
    "saturation": 0,
    "sharpness": 0,
    "video_denoise": true
}
```

### GET `/api/record`

Triggers a recording event. The event will be padded both before and after the trigger event by the value defined in `MOTION_RECORDING_PADDING` in `watchtower_config.json`. An example of this file is located in [watchtower_config_example.json](watchtower/config/watchtower_config_example.json).

The response will be a 204 No Content.

### GET `/api/recordings`

Returns a listing of all recordings that Watchtower has saved to disk. Each `day` string will match the `DIR_DAY_FORMAT` in the watchtower_config.json file. Each time string in the day's `times` array will match the `DIR_TIME_FORMAT`.

200 Response JSON:
```JSON
[

    {
        "day": "2020-09-07",
        "times": [
            "12.25.43",
            "12.13.12"
        ]
    },
    {
        "day": "2020-09-06",
        "times": [
            "18.21.52",
            "14.28.26",
            "13.39.21",
            "13.02.22",
            "10.51.26",
            "10.21.05"
        ]
    }
]
```

### GET `/api/recordings/:day`

Returns a listing of all recordings for the specified day. The `day` path element must match the `DIR_DAY_FORMAT` in the watchtower_config.json file.

200 Response JSON:
```JSON
[
    "18.21.52",
    "14.28.26",
    "13.39.21",
    "13.02.22",
    "10.51.26",
    "10.21.05"
]
```

### DELETE `/api/recordings/:day`
### DELETE `/api/recordings/:day/:time`

If just a `day` is supplied, this will delete all of the recordings for the specified day. If both a `day` and `time` are supplied, this will delete only a single recording matching the day and time.

When successful, the response will be a 204 No Content.

### GET `/api/recordings/:day/:time/trigger`

Returns the jpeg image capturing the motion event that triggered the recording for the specified day and time.

The response will be a 200 containing the jpeg file data.

### GET `/api/recordings/:day/:time/recording`

Returns the h264 video file containing the entire recording that occurred at the specified day and time.

The response will be a 200 containing the h264 file data.

### GET `/mjpeg`

_This one is treated as part of the web app, but listing it here for completeness._

Starts an MJPEG stream that will send JPEG frames as a multipart response. This will continue to stream until the connection is closed. An optional `encoding` URL parameter can be supplied with a value of `base64`, which will base64 encode each response's jpeg data.

The response will be a 200. Each part will have a Content-Type of `image/jpeg` and the raw JPEG data will be delineated by a `-- FRAME` boundary string.

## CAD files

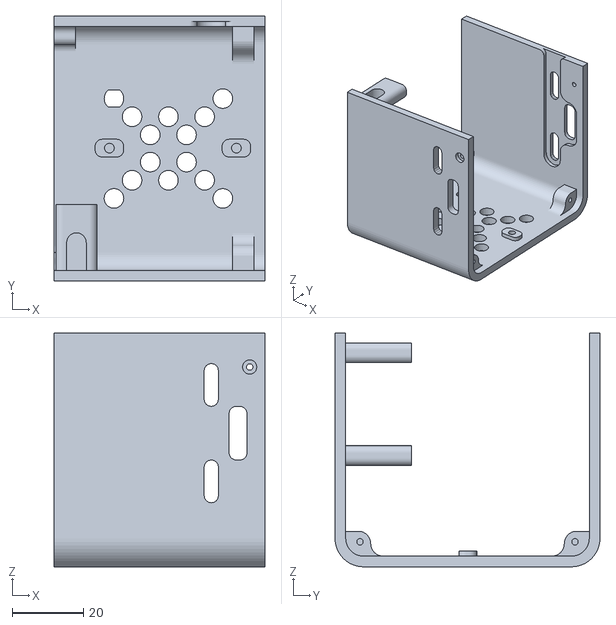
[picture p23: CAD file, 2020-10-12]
ancillary/case/v3/parts/v3_chassis.stl
59.0 x 74.2 x 65.4

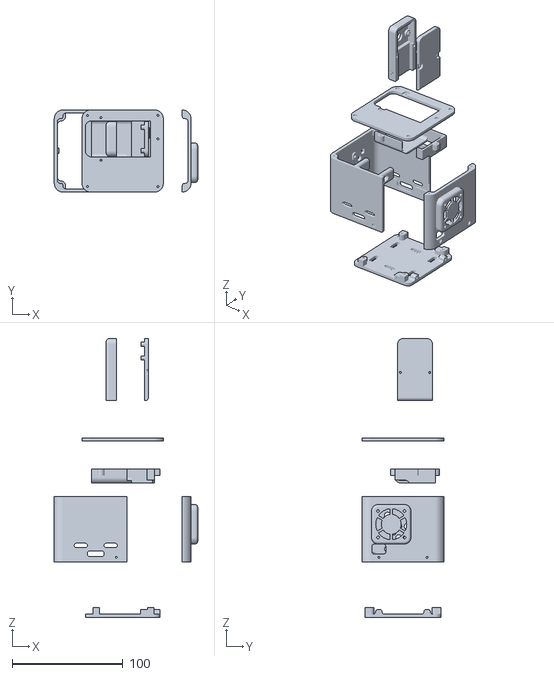
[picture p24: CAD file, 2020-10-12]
ancillary/case/v3/parts/v3_all_parts.stl
129.4 x 74.2 x 251.6

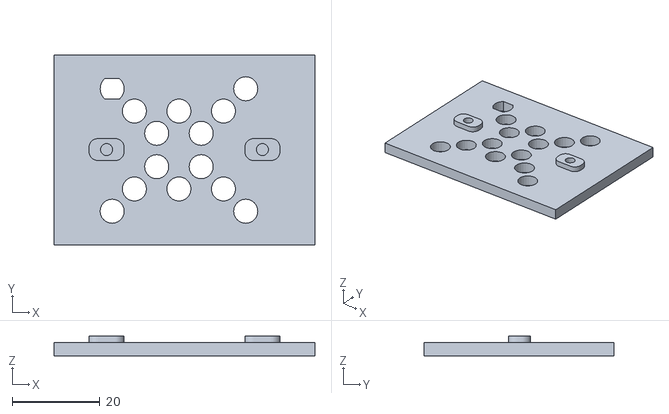
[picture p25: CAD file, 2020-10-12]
ancillary/case/v3/parts/v3_front_test_plate.stl
59.6 x 43.4 x 4.50

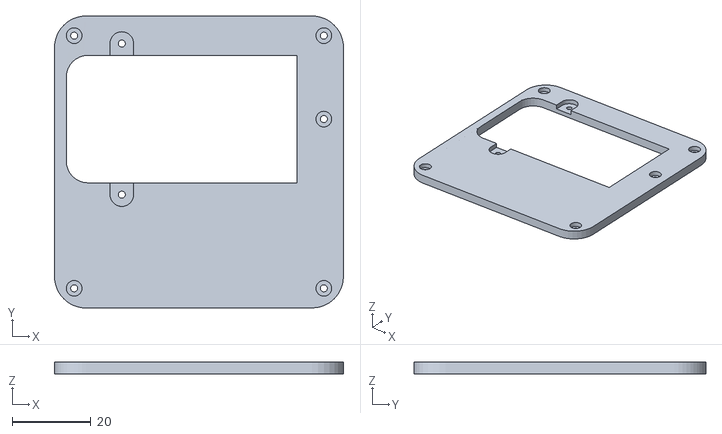
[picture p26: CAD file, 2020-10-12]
ancillary/case/v3/parts/v3_top.stl
73.4 x 74.2 x 3.01

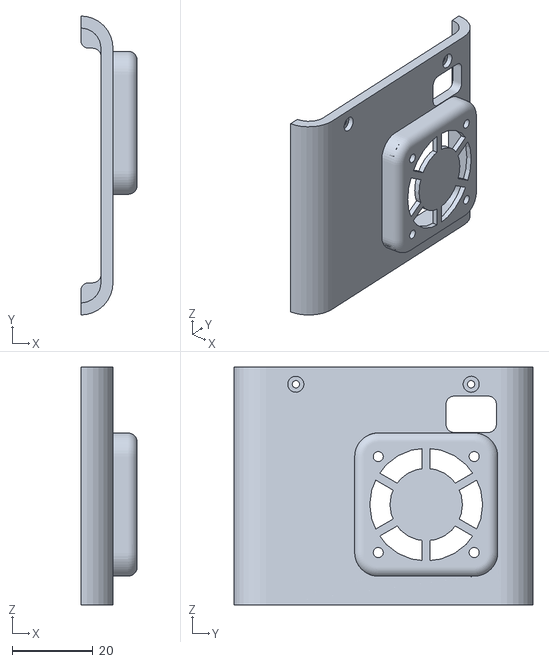
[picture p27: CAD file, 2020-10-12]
ancillary/case/v3/parts/v3_back.stl
14.0 x 74.2 x 59.0

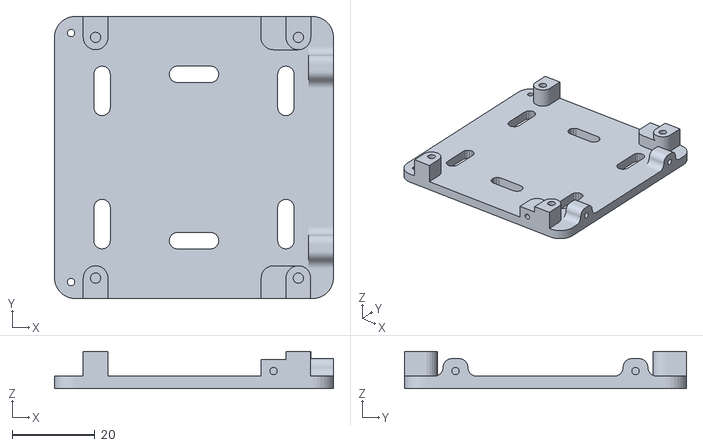
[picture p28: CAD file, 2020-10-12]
ancillary/case/v3/parts/v3_bottom.stl
67.4 x 68.2 x 9.00

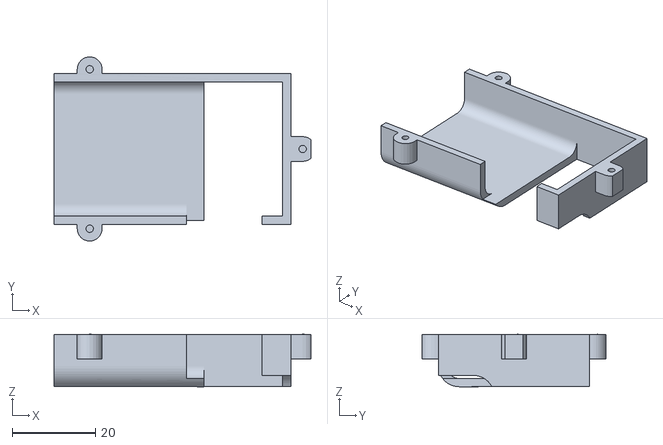
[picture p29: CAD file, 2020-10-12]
ancillary/case/v3/parts/v3_camera_cradle.stl
61.9 x 44.4 x 12.7

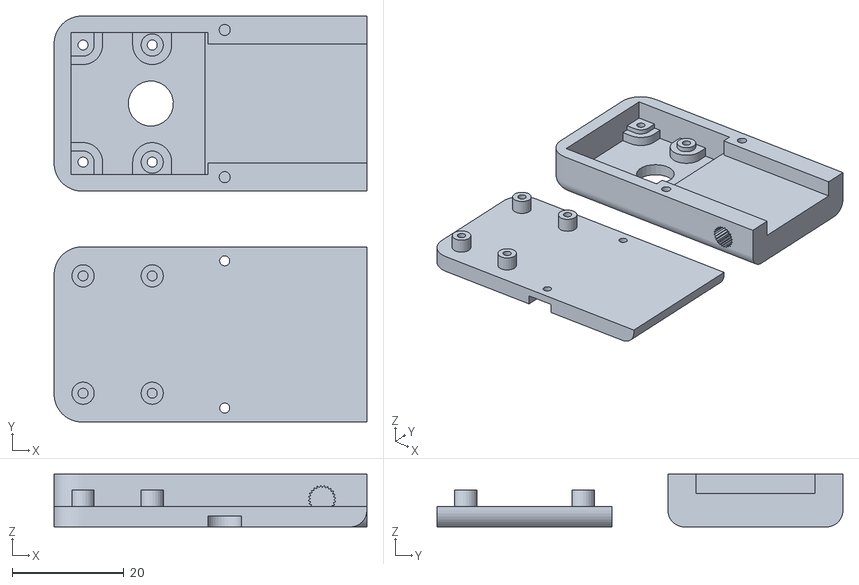
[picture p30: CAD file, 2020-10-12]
ancillary/case/v3/parts/v3_camera_case.stl
56.1 x 72.8 x 9.50

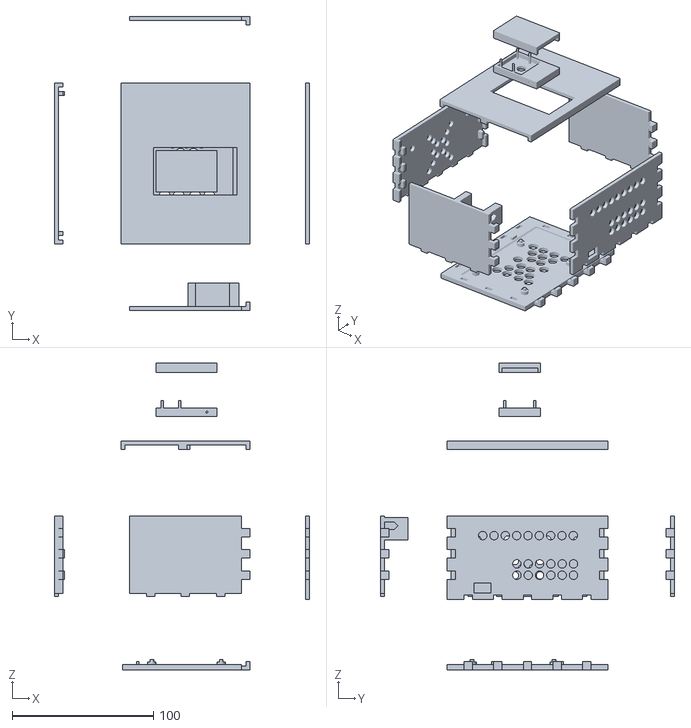
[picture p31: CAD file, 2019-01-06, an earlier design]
ancillary/case/v1/PiSecurityCamCase.stl
180.4 x 208.0 x 217.0

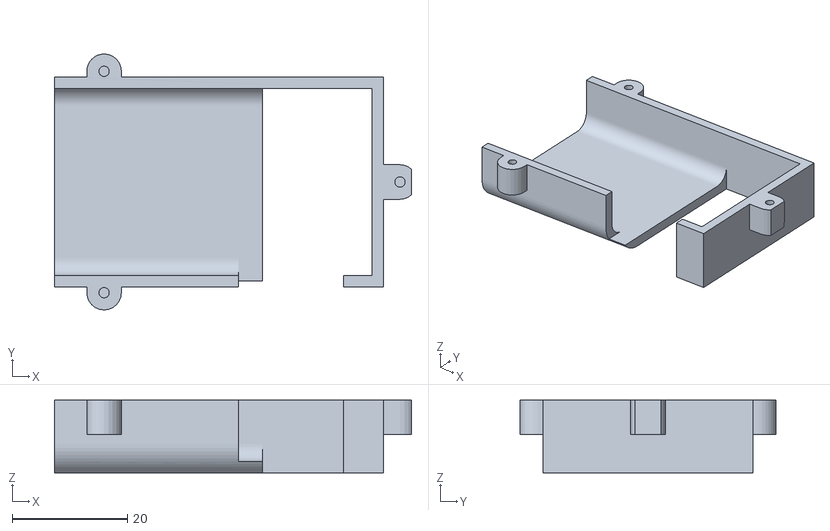
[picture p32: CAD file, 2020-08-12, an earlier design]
ancillary/case/v2/parts/v2_camera_cradle.stl
61.9 x 44.4 x 12.7

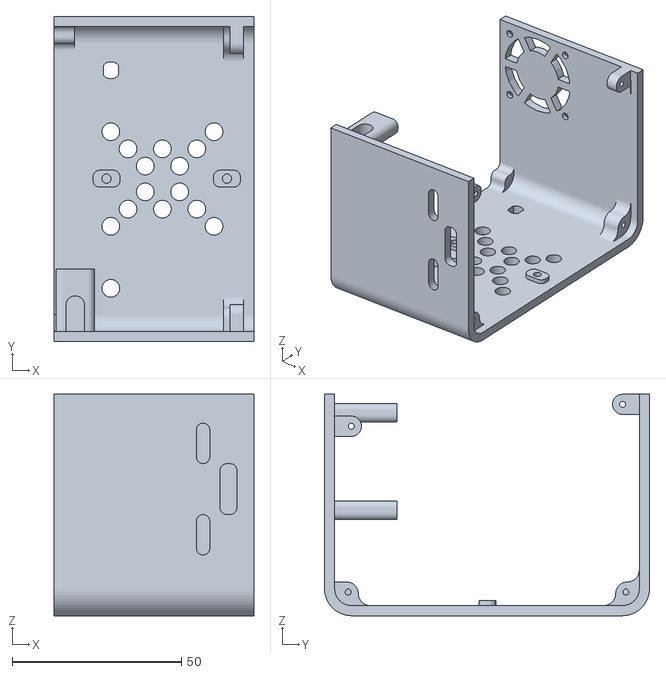
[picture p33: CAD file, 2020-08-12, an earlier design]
ancillary/case/v2/parts/v2_chassis.stl
59.0 x 96.0 x 65.4

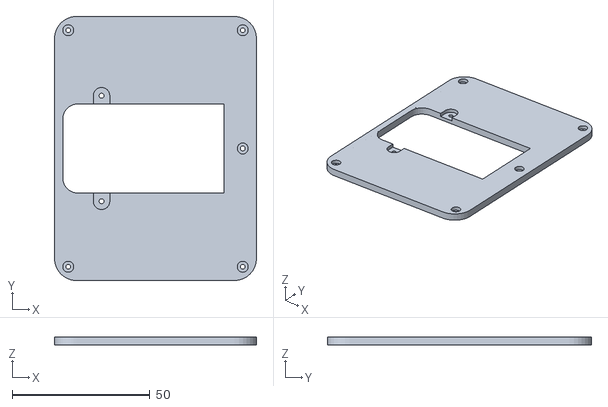
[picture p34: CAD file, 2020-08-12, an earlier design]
ancillary/case/v2/parts/v2_top.stl
73.4 x 96.0 x 3.01

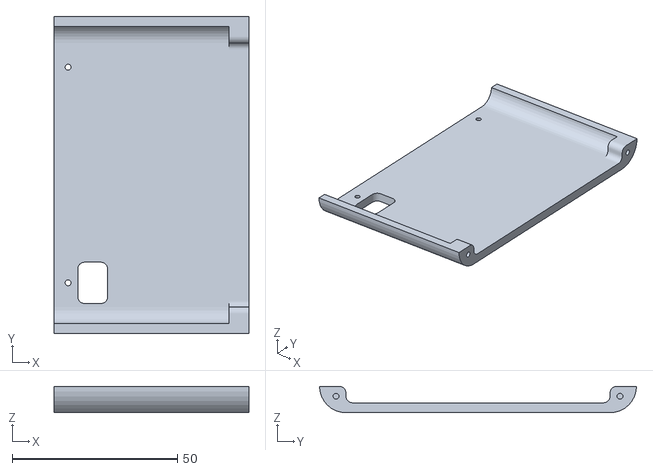
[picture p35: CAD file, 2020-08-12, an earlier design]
ancillary/case/v2/parts/v2_back.stl
59.0 x 96.0 x 8.00

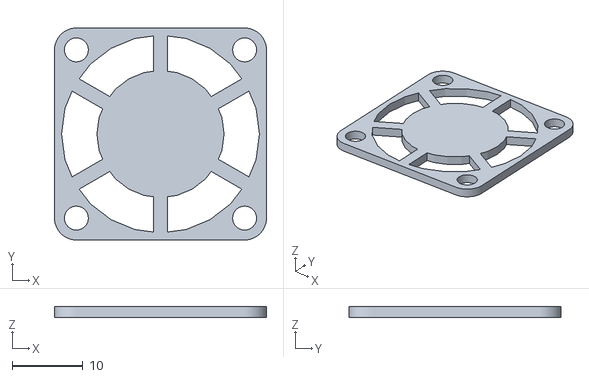
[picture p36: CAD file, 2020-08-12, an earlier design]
ancillary/case/v2/parts/v2_fan_cover.stl
30.0 x 30.0 x 1.50

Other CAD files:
ancillary/case/v2/parts/v2_camera_case.stl
ancillary/case/v2/parts/v2_all_parts.stl
ancillary/case/v2/parts/v2_bottom.stl

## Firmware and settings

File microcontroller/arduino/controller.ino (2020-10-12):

/*
  controller
  
  Reads the analog light in the room and adjusts IR LEDs to the
  appropriate brightness. Also controls a servo to expose and hide
  the camera.
  
  Communicates serially with a microcontroller using RX_PIN and
  TX_PIN, supplying the room light value on a scale of 0-100. This
  connection can receive on/off commands to enable or disable the LEDs.
  This can also receive servo commands to move a servo to a desired
  angle.
  
  This program is designed to run on an Atmel ATtiny84 or 44 and
  should consume about 3.6KB of program space when link time optimization
  is enabled.
  
  Created by John Newman, June 20, 2020.
  MIT License.
*/

#include <SoftwareSerial.h>
#include "TinyServo.h"

const unsigned int BAUD_RATE = 19200;
const unsigned int RX_PIN = 2;
const unsigned int TX_PIN = 1;

const unsigned int LED_PWM_PIN = 7;  // For large number of LED's, use a transistor.
const unsigned int LIGHT_SENSOR_PIN = A3;

// The analogRead light value (0-255) is constrained between MIN and MAX.
const byte MIN_LIGHT_READING = 40;
const byte MAX_LIGHT_READING = 100;

const unsigned int SERVO_PIN = 5;
const unsigned int SERVO_MIN_PULSE_WIDTH = 500;
const unsigned int SERVO_MAX_PULSE_WIDTH = 2300;

// The valid commands received from RX_PIN.
const char IR_ON_COMMAND[] = "ir_on";
const char IR_OFF_COMMAND[] = "ir_off";
const char SERVO_ANGLE_COMMAND[] = "servo_angle_";

// The valid messages sent over TX_PIN.
const char SUCCESS_MESSAGE[] = "ok\n";
const char REBOOT_MESSAGE[] = "reboot\n";
const char BRIGHTNESS_PREFIX[] = "bright: ";

// Length of maximum received string. "servo_angle_1xx\n"
const byte MAX_COMMAND_LENGTH = 16;

SoftwareSerial comm(RX_PIN, TX_PIN);

TinyServo servo;

// Start in the "off" state.
bool shouldRunIR = false;

// Used to keep track of when the last transmission
// occurred. This keeps us from clogging the TX line
// while also avoiding calls to delay().
unsigned long lastTransmission = 0;


void setup() {
  pinMode(LED_PWM_PIN, OUTPUT);
  pinMode(LIGHT_SENSOR_PIN, INPUT);
  comm.begin(BAUD_RATE);
  comm.print(REBOOT_MESSAGE);
  servo.attach(SERVO_PIN, SERVO_MIN_PULSE_WIDTH, SERVO_MAX_PULSE_WIDTH);
}

void loop() {
    char commandBuffer[MAX_COMMAND_LENGTH] = "";
    receiveCommand(commandBuffer);
    if (strlen(commandBuffer) > 0) {
      processServoCommand(commandBuffer);
      processIRCommand(commandBuffer);
    }

    if (!shouldRunIR) {
      digitalWrite(LED_PWM_PIN, LOW);
      return;
    }

    if (millis() - lastTransmission >= 500) {
      updateLED(readLight());
      lastTransmission = millis();
    }
}

/**
  Reads commands separated by newlines on RX_PIN.
  
  @return the command string or an empty array.
*/
void receiveCommand(char *commandBuffer) {
  comm.listen();
  if (comm.available()) {
    comm.readBytesUntil('\n', commandBuffer, MAX_COMMAND_LENGTH);
  }
}


/**
 * Parses servo commands, extracting the angle information
 * and passing that along to the TinyServo instance.
 * 
 * @param command The command string to check.
 */
void processServoCommand(const char *command) {
  if (strstr(command, SERVO_ANGLE_COMMAND) == NULL) {
    return;
  }

  const char *angleString = &command[strlen(SERVO_ANGLE_COMMAND)];
  if (strlen(angleString) > 0) {
    byte angle = atoi(angleString);
    servo.writeAngle(angle);
    sendSuccessMessage();
  }
}

/**
 * Parses infrared commands, flipping the shouldRunIR flag
 * if one is found.
 * 
 * @param command The command string to check.
 */
void processIRCommand(const char *command) {
  if (strcmp(command, IR_ON_COMMAND) == 0) {
    shouldRunIR = true;
    sendSuccessMessage();
  } else if (strcmp(command, IR_OFF_COMMAND) == 0) {
    shouldRunIR = false;
    sendSuccessMessage();
  }
}

/**
 * Reads the analog light value on LIGHT_SENSOR_ANALOG_PIN.
 * 
 * @return The clamped/constrained light value.
 */
byte readLight() {
  byte light = analogRead(LIGHT_SENSOR_PIN);
  return constrain(light, MIN_LIGHT_READING, MAX_LIGHT_READING);
}

/**
  Updates the brightess of the LEDs using PWM. Also sends
  the light value from 0-100 to TX_PIN.

  @param lightValue The analog light reading from 0 to 255.
*/
void updateLED(byte lightValue) {
  // Reverse it and map to 0-255 scale.
  byte pwmValue = map(lightValue, MIN_LIGHT_READING, MAX_LIGHT_READING, 255, 0);
  analogWrite(LED_PWM_PIN, pwmValue);
  comm.print(BRIGHTNESS_PREFIX);
  comm.print(map(pwmValue, 0, 255, 100, 0));
  comm.print('\n');
}

/**
 * Used anytime a success message is transmitted.
 */
void sendSuccessMessage() {
  comm.print(SUCCESS_MESSAGE);
}

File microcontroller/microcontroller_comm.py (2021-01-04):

import asyncio
import serial
import time
import queue

# Transmitted commands
INFRARED_ON_COMMAND = "ir_on"
INFRARED_OFF_COMMAND = "ir_off"
SERVO_COMMAND_PREFIX = "servo_angle_"

# Known responses
SUCCESS_MESSAGE = "ok"
REBOOT_MESSAGE = "reboot"
BRIGHTNESS_PREFIX = "bright: "


class MicrocontrollerComm:
    """
    A class that can communicate with a microcontroller to move a servo and
    enable or disable infrared lighting. Serial commands are transmitted using
    utf-8 encoding.
    """

    def __init__(self,
                 port,
                 baudrate,
                 transmission_interval=2):
        """
        Sets up the serial connection but does not start data transmission.

        :param port: The port of the serial connection, like "/dev/serial0".
        :param baudrate: The baud rate of the serial connection.
        :param transmission_interval: The interval at which commands are sent
        over the serial line.
        """
        super(MicrocontrollerComm, self).__init__()
        self.__controller = serial.Serial(port=port,
                                          baudrate=baudrate,
                                          parity=serial.PARITY_NONE,
                                          stopbits=serial.STOPBITS_ONE,
                                          bytesize=serial.EIGHTBITS,
                                          timeout=1)
        self.__command_queue = queue.Queue(2)
        self.__brightness = -1.0
        self.__infrared_running = False
        self.__transmission_interval = transmission_interval
        self.__last_transmission_time = 0

    @property
    def brightness(self):
        """
        :return: The brightness value read from the serial connection.
        """
        return self.__brightness

    @brightness.setter
    def brightness(self, value):
        self.__brightness = value

    @property
    def infrared_running(self):
        return self.__infrared_running

    @infrared_running.setter
    def infrared_running(self, value):
        old_value = self.__infrared_running
        self.__infrared_running = value
        
        # Send the command only if necessary.
        if value == True and old_value == False:
            self.__enqueue_command(INFRARED_ON_COMMAND)
        elif value == False and old_value == True:
            self.__enqueue_command(INFRARED_OFF_COMMAND)

    def set_servo_angle(self, angle):
        self.__enqueue_command(SERVO_COMMAND_PREFIX + str(angle))
    
    def __enqueue_command(self, command):
        """
        Attempts to add the command string to the queue. If the queue is full,
        new commands take priority and the oldest command is removed.
        :param command: The command string to enqueue.
        """
        try:
            self.__command_queue.put(command)
        except queue.Full:
            print('Queue is full! Removing an element.')
            try:
                self.__command_queue.get_nowait()
            except queue.Empty:
                pass
            self.__enqueue_command(command)  # Recursively try again.

    def __write_command(self, command):
        """
        Transmits the command string over the serial connection.
        :param command: The command string to transmit.
        """
        total_sent = 0
        while total_sent < len(command) and len(command) > 0:
            sent = self.__controller.write((command + '\n').encode())
            if sent == 0:
                raise RuntimeError('Failed to write to serial port.')
            total_sent += sent
        print(f'Transmitted \"{command}\".')

    def __process_input(self):
        """
        Checks for input on the serial connection and handles any messages
        received. Returns True if the response was a success message. These
        should be received after transmitting a command.
        """
        if self.__controller.in_waiting > 0:
            response = self.__controller.readline().decode("utf-8").strip()
            if response == SUCCESS_MESSAGE:
                print(f'Received an \"{SUCCESS_MESSAGE}\" message!')
                return True
            elif response == REBOOT_MESSAGE:
                print('Microcontroller has rebooted.')
            elif response.startswith(BRIGHTNESS_PREFIX):
                try:
                    self.__infrared_running = True
                    self.brightness = int(response[len(BRIGHTNESS_PREFIX):])
                except Exception as e:
                    print(f'Exception parsing brightness: {e}')
        return False

    async def loop(self):
        """
        Infinitely loops, checking for new commands to transmit over the serial
        connection while also processing any input data from the connection.
        """
        while True:
            wait_for_success_message = False

            # Only transmit at the transmission interval so that the receiving
            # end has time to process each command.
            if time.time() - self.__last_transmission_time >= 1.0/self.__transmission_interval:
                try:
                    # Attempt to transmit any new commands
                    command = self.__command_queue.get_nowait()
                    self.__write_command(command)
                    wait_for_success_message = True
                    self.__last_transmission_time = time.time()
                except queue.Empty:
                    pass
                except RuntimeError as e:
                    print(f'Runtime exception: {e}')

            # Now handle any input
            if not self.__process_input() and wait_for_success_message:
                # Wait for the next transmission
                await asyncio.sleep(1.0/self.__transmission_interval)
                if not self.__process_input():
                    print(f'Did not receive success code for command \"{command}\". Retrying.')
                    self.__enqueue_command(command)
            
            await asyncio.sleep(1.0/self.__transmission_interval/2.0)

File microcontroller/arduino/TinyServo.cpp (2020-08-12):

/*
  TinyServo.cpp - Tiny library for controlling servos on
  the Atmel ATtiny24/44/84.
  Created by John Newman, June 28, 2020.
  MIT License.
*/

#include "TinyServo.h"

const unsigned int PIN_A = 6;
const unsigned int PIN_B = 5;
const unsigned int PULSE_HZ = 50;
const unsigned int TIMER_TOP = 20000;
const unsigned int MIN_PULSE_WIDTH = 1000; // 1ms
const unsigned int MAX_PULSE_WIDTH = 2500; // 2.5ms

static TinyServo *servos[2];

TinyServo::TinyServo() { }

void TinyServo::attach(byte pin) {
  this->attach(pin, MIN_PULSE_WIDTH, MAX_PULSE_WIDTH);
}

void TinyServo::attach(byte pin, unsigned int minPulseWidth, unsigned int maxPulseWidth) {

  byte index;
  switch (pin) {
    case PIN_A:
      index = 0;
      break;
    case PIN_B:
      index = 1;
      break;
    default:
      // Unsupported pin.
      return;
  }

  if (servos[index]) {
    return;
  }
  servos[index] = this;

  /*
   Bits WGM10 WGM11 WGM12 WGM13
            0     1     1     1
     Uses fast PWM with TOP value set to value of register ICR1         
   
   Bits CS10 CS11 CS12
           0    1    0
     Sets prescaler to 8.
   
   PWM frequency = Timer clock / prescaler / TOP value
   PWM Freq = 8 MHz / 8 / 20000
            = 50 Hz
  */
  cli(); // Disable interrupts while changing registers.
  TCCR1A = _BV(WGM11);
  TCCR1B = _BV(CS11) | _BV(WGM12) | _BV(WGM13);
  ICR1 = TIMER_TOP;
  sei(); // Reenable interrupts.
  
  _minPulseWidth = minPulseWidth;
  _maxPulseWidth = maxPulseWidth;
  _pin = pin;
  pinMode(pin, OUTPUT);
}

void TinyServo::writeAngle(byte angle) {
  angle = constrain(angle, 0, 180);
  cli();
  *(_connect()) = map(angle, 0, 180, _minPulseWidth, _maxPulseWidth);
  sei();
}

volatile unsigned int* TinyServo::_connect() {
  /*
   Bits COM1n1 COM2n1
             1     0
   Sets OC1n to low on compare match with OCR1n. Sets to high at bottom.
   n=A if pin==PIN_A, n=B if pin==PIN_B.
  */
  switch (_pin) {
    case PIN_A:
      TIMSK1 |= _BV(OCIE1A);
      TCCR1A |= _BV(COM1A1);
      return &OCR1A;
    case PIN_B:
      TIMSK1 |= _BV(OCIE1B);
      TCCR1A |= _BV(COM1B1);
      return &OCR1B;
  }
  return NULL;
}

void TinyServo::_disconnect() {
  switch (_pin) {
    case PIN_A:
      TIMSK1 &= ~_BV(OCIE1A);
      TCCR1A &= ~_BV(COM1A1);
      break;
    case PIN_B:
      TIMSK1 &= ~_BV(OCIE1B);
      TCCR1A &= ~_BV(COM1B1);
      break;
  }
}

void TinyServo::interrupt() {
  _pulseCount++;
  if (_pulseCount >= PULSE_HZ) {
    cli();
    _disconnect();
    sei();
    _pulseCount = 0;
  }
}

/** Timer1 interrupt handlers **/

ISR(TIMER1_COMPA_vect)  {
  if (servos[0]) {
    servos[0]->interrupt();
  }
}

ISR(TIMER1_COMPB_vect)  {
  if (servos[1]) {
    servos[1]->interrupt();
  }
}

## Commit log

2018-10-21 Adding a command receiver to listen for socket commands.
2018-10-21 Supplying resolution and framerate to the camera initializer.
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2018-10-21 Now breaking when finding the first sps header. No longer stopping the read when the stream position matches the current read position.
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2018-10-21 Changing the stream saver to read up to the latest frame. read_from_stream is now an instance method.
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2018-10-24 Now using a json config file instead of supplied arguments. Adding extra json fields for date formats, rotation, and framerate. Moving the location of the init_camera function.
2018-10-24 Adding a StreamSaver subclass just for the camera stream. Does a better job calculating the start position, basing it on frame timestamps.
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2018-10-25 No longer writing each motion frame to dropbox.
2018-10-28 Now read works as the circular buffer is continually appended to. The last frame is stored across read operations and the position recomputed each read.
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2018-10-29 Now updating the frame as the loop iterates in case the stream no longer contains the frame we're searching for.
2018-10-30 Adding a socket writer and an MJPEG streamer.
2018-10-30 Renaming the CommandReceiver to CommandServer. Now utilizing the socket writer class and supporting MJPEG streaming.
2018-11-03 Now waiting on the camera to update the timestamp.
2018-11-03 Adding formatted printing to stderr. Adding documentation and more error codes and messages.
2018-11-03 Using a minimum mjpeg rate. Switching the stream command to be an endpoint and now using the supplied fps parameter.
2018-11-04 Wrapping the write in a try/catch block. Closing the socket if there is an exception.
2018-11-04 FPS is now handled correct as a framerate per sec.
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2018-11-04 Cleaning up the JSON and adding an API key to connect with the camera.
2018-11-05 Now checking the MJPEG server's status code. Adding failsafes in case data fails to load.
2018-11-07 Adding config and controller modules. Adding a Camera class that has the ability to make basic GET requests to its associated camera.
2018-11-07 Fixing the initialization to create a Camera object.
2018-11-08 Adding a SafeCamera class that locks the camera while it captures into a stream.
2018-11-10 Adding documentation. Now the constructor accepts a camera instance.
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2018-11-10 Removing the running callbacks. The camera now has a should_monitor flag. Using new CommandServer init syntax.
2018-11-10 Removing the callbacks and instead using the should_monitor property on the camera.
2018-11-10 Now starting the server after the camera is initialized.
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2018-11-11 Adding servos to the camera that can hide or expose the camera.
2018-11-11 Adding a servo socket writer that can communicate with PiServoServer.
2018-11-11 Now hiding and exposing the camera upon API commands.
2018-11-11 Now hiding the camera once the stream ends.
2018-11-21 The camera name now has a space after it.
2018-11-25 Adding support for sending network requests to multiple cameras. Adding a threaded class to handle each request.
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2018-11-25 Adding "camera" as a supported parameter. Now finding the matching camera and using this to create the FPS and connection.
2018-11-25 Adding a CGI script to return every camera name.
2018-11-26 Now using a 404 for an unfound camera.
2018-11-26 Now allowing the camera some time after resuming to avoid erroneous motion events from servos.
2018-12-01 Now using a formatted string for the camera annotation.
2018-12-01 Adding an ir_serial class to communicate with an infrared led controller.
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2018-12-02 Adding room brightness data to the camera annotations.
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2018-12-31 Adding the Fritzing diagram.
    [ArduinoHat.fzz]
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2019-01-06 Adding 3d case model.
    [PiSecurityCamCase.stl]
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2020-04-26 Upgrading to Python 3. Adding a new endpoint to trigger a recording and fixing a bug with finding the starting camera frame.
    [disk_writer.py, dropbox_writer.py, socket_writer.py]
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2020-05-22 Switching to an example, easily replaceable path section.
2020-05-22 Now saving local recordings the a "recordings" folder. Dropbox still goes to a directory named after the camera.
2020-06-29 Converting to an ATTiny84 and adding new serial commands. Adding a TinyServo library to control servos on the ATTiny84 with Timer0.
2020-07-19 TinyServo now uses the interrupt handler to disconnect the servo after a period of time.
2020-07-26 Rewriting the ir_serial module to be microcontroller_comm. This now handles servo movement. Moving servo references out of the camera class and removing the ServoSocketWriter.
2020-07-26 Adding a Servo class and updating the configuration file with a microcontroller section instead of separate serial and servo sections.
2020-07-26 Updating the messages sent over the serial line. Tweaking the delay between loops. Switching the light sensor to the analog 3 pin.
2020-07-26 Updating the README to reflect the changes to the servo and microcontroller implementations.
2020-07-28 Adding better documentation and switching to char array strings and byte types to reduce the memory footprint.
2020-07-28 Using the volatile keyword for the compare registers returned from _connect. Adding a missing return statement.
    [TinyServo.cpp]
2020-08-02 Renaming the Arduino section to "hardware" and updating it with the latest Fritzing schematic. Versioning the 3D cases.
    [ArduinoHat.fzz, PiSecurityCamCase.stl, WatctowerHAT.fzz]
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2020-08-02 Adding the v2 case's stl files.
    [v2_all_parts.stl, v2_back.stl, v2_bottom.stl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]
2020-08-03 Using the correct import statement for Servo.
2020-08-03 Adding missing servo named parameter.
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2020-08-03 Bug fixes to add self to instance methods and fixing logic errors in the MicrocontrollerComm class.
    [microcontroller_comm.py]
2020-08-03 Adding a setter for the servo property. Fixing json parsing for the microcontroller.
2020-08-09 Refactoring the dropbox uploader to not block when uploading video clips, which could cause data loss as the camera's circular queue was overwritten before the data could be uploaded. Now using pools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
2020-08-10 No longer using multiple threads if the file_chunk_size is negative. This allows us to only allocate one thread when uploading jpgs.
    [dropbox_writer.py]
2020-08-10 Improving the speed of copying the camera's stream's bytes. Adding more performance logs.
2020-08-17 Now the default file chunk size is a constant and in megabytes. Adding a method to query all threads to make sure writing is done. Adding a way to use a different uploader for testing.
2020-08-23 Adding a conftest file for shared fixtures. This file also sets up the path for watchtower.
    [test_dropbox_writer.py]
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2020-10-11 Adding a v3 case for the Raspberry Pi 3A+.
    [v3_all_parts.stl, v3_back.stl, v3_bottom.stl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]
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2020-10-11 Updating Fritzing diagram.
    [WatctowerHAT.fzz]
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2021-01-01 When closing, no longer creating an empty file if the byte pool is empty.
    [dropbox_writer.py]
2021-01-01 Now properly sorting file names over 9. No longer running python from venv.
    [test_dropbox_writer.py]
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2021-01-13 Fixing a memory leak that caused bytes to accumulate.
    [http_writer.py]
2021-01-13 Fixing memory leak that caused bytes to accumulate.
    [http_writer.py]
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2021-05-23 Adding downstream CA to env file. Fixing downstream endpoint.
    [downstream.py]
